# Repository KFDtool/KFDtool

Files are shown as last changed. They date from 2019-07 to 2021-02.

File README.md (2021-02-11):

# [KFDtool](https://github.com/KFDtool/KFDtool)

Open Source P25 Key Fill Device

Compliant with P25 standards (TIA-102.AACD-A)

Purchase Hardware: [online store](https://kfdtool.com/store)

Download Software: [latest release](https://github.com/KFDtool/KFDtool/releases)

Release Notifications: [subscribe](https://kfdtool.com/newsletter)

Demonstration: [video](https://www.youtube.com/watch?v=Oioa3xTQoE0)

Software Manual: [view](doc/KFDtool_Manual.pdf)

Security Considerations: [view](doc/SECURITY_CONSIDERATIONS.md)

Features
--------

**Key Fill Device (KFD)**

The KFDtool software supports KFD features through the KFDtool hardware adapter (TWI/3WI/Three Wire Interface), as well as through a IP (UDP) connection (DLI/Data Link Independent interface).

Keys and groups of keys can be saved to an AES-256 encrypted key container file, which can then be selected and loaded into a target device in one operation.

Supported Manual Rekeying Features (TIA-102.AACD-A)

* 2.3.1 Keyload
* 2.3.2 Key Erase
* 2.3.3 Erase All Keys
* 2.3.4 View Key Info
* 2.3.5 View Individual RSI
* 2.3.6 Load Individual RSI
* 2.3.7 View KMF RSI
* 2.3.8 Load KMF RSI
* 2.3.9 View MNP
* 2.3.10 Load MNP
* 2.3.11 View Keyset Info
* 2.3.12 Activate Keyset

Motorola refers to the P25 standard 3 wire interface (3WI) keyload protocol as ASTRO 25 mode or CKR mode.

The legacy Motorola proprietary keyloading formats SECURENET and ASN (Advanced SECURENET) are **NOT** supported by KFDtool. PID mode is also used to refer to ASN mode.

Key validators/generators are available for the following algorithms:

* AES-256 (Algorithm ID 0x84)
* DES-OFB (Algorithm ID 0x81)
* DES-XL (Algorithm ID 0x9F)
* ADP/RC4 (Algorithm ID 0xAA)

**Mobile Radio (MR) Emulator**

The KFDtool software only supports MR Emulator features through the KFDtool hardware adapter (TWI/3WI/Three Wire Interface) at this time.

This mode allows another keyloader to be connected to the KFDtool, and the keys retrieved.

Supported Manual Rekeying Features (TIA-102.AACD-A)

* 2.3.1 Keyload

Radio Compatibility
-------------------

*Any statements of compatibility do not imply endorsement by the vendor. Testing has not been performed by the vendor themselves.*

**A detailed list of compatible radios and adapters is available [here](doc/RADIO_COMPATIBILITY.md).**

Radios that are compatible with Motorola KVL3000/KVL3000+/KVL4000/KVL5000 keyloaders in ASTRO 25 mode should be compatible with KFDtool.

Keyloading cables made for other radios with MX (Motorola KVL) connectors can be modified by soldering an AC101 or AC102 Hirose pigtail in parallel with the MX connector according to [these](doc/MX_CONN_MOD_NOTES.md) instructions.

Operations encapsulated with encryption (commonly referred to as FIPS mode) are not supported at this time for either the KFD or MR emulation modes.

Hardware
--------

Assembled and tested KFDtool hardware is available from me directly. I can ship internationally. Please visit the [online store](https://kfdtool.com/store) to place an order.

**Proceeds from hardware sales enables me to further develop the software.**

| Part Number | Description |
| :---: | --- |
| KFD100 | Single Hirose port USB key fill device (includes 1 m / 3 ft USB A to USB B cable) |
| AC100 | 6 pin male plug Hirose to 6 pin male plug Hirose cable (0.5 m / 1.5 ft) |
| AC101 | 6 pin male plug Hirose pigtail for custom cables (0.5 m / 1.5 ft) |
| AC102 | 6 pin female jack Hirose pigtail for custom cables (0.5 m / 1.5 ft) |
| AC103 | Motorola R2670 compatible adapter (0.15 m / 6 in) |
| AC104 | Kenwood KPG-115 compatible adapter (0.15 m / 6 in) |
| AC105 | 4 way female jack passive Hirose splitter |
| AC106 | Kenwood KPG-93 compatible adapter (0.15 m / 6 in) |
| AC107 | Motorola XTS4000 compatible adapter (0.15 m / 6 in) |
| AC108 | Aeroflex/IFR 2975 compatible adapter (0.15 m / 6 in) |
| AC109 | Harris XG-100P/XL-150P/XL-185P/XL-200P compatible adapter |

OS Compatibility
----------------

* KFDtool software supports 32-bit and 64-bit Windows 7, Windows 8.1, and Windows 10

* The .NET Framework 4.7.2 or later compatible must be installed

* **The use of a virtual machine with USB passthrough is NOT supported at this time**
    * Changing the USB controller from USB 2.0 mode to USB 3.0 mode has been reported to resolve the issue
    * Do not attempt to update the adapter firmware or initialize an adapter using USB passthrough

Documentation
-------------

* [Software Changelog](doc/SW_CHANGELOG.txt)
* [Firmware Changelog](doc/FW_CHANGELOG.txt)
* [Hardware Changelog](doc/HW_CHANGELOG.txt)
* [Radio Compatibility](doc/RADIO_COMPATIBILITY.md)
* [TWI Cable Assembly Notes](doc/TWI_CABLE_ASSY_NOTES.md)
* [MX Connector Modification Notes](doc/MX_CONN_MOD_NOTES.md)
* [Developer Notes](doc/DEV_NOTES.md)
* [Security Considerations](doc/SECURITY_CONSIDERATIONS.md)

Contributors
------------

* [Daniel Dugger](https://github.com/duggerd)
* [Matt Ames](https://github.com/mattames)

License / Legal
---------------

KFDtool software, firmware, and hardware is distributed under the MIT License (see [LICENSE.txt](LICENSE.txt)).

KFDtool is a trademark of Florida Computer and Networking, Inc.

All product names, trademarks, registered trademarks, logos, and brands are property of their respective owners. All company, product, and service names used are for identification purposes only. Use of these names, trademarks, logos, and brands does not imply endorsement.

Note about hardware:

I request that no one else manufactures identical or compatible units **and sells them to others while I am still doing so** - I have put quite a bit of my own money into developing this hardware. I am totally fine with someone making a unit for themselves or a couple of extras to give to their friends, just that they don't charge for them. Proceeds from hardware sales enables me to further develop the software.

Included open-source components:

Software (see [doc/SW_LICENSE.txt](doc/SW_LICENSE.txt)):

* [NLog](https://github.com/NLog/NLog) - MIT License
* [Mono.Options](https://github.com/mono/mono/blob/master/mcs/class/Mono.Options/Mono.Options/Options.cs) - MIT License
* [HidLibrary](https://github.com/mikeobrien/HidLibrary) - MIT License
* [Microsoft Reference Source](https://github.com/microsoft/referencesource) - MIT License
* [InnovasubBSL430](https://github.com/corentinaltepe/InnovasubBSL430) - GPL v3+ License
* Texas Instruments - BSD 3 Clause License

Firmware (see [doc/FW_LICENSE.txt](doc/FW_LICENSE.txt)):

* Texas Instruments - BSD 3 Clause License

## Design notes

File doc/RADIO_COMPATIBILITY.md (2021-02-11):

# Compatibility

*Any statements of compatibility do not imply endorsement by the vendor. Testing has not been performed by the vendor themselves.*

## Three Wire Interface (TWI)

### Key Fill Device (KFD)

#### Adapter Compatibility

A vendor specific adapter or cable is required for most radios.

**The following adapters or cables are tested compatible with KFDtool:**

| Adapter | Device |
| --- | --- |
| KFDtool AC100 + KFDtool AC103 | Motorola R2670A/B Communications System Analyzer |
| KFDtool AC100 + KFDtool AC104 | Kenwood NX-5700/5800/5900 Mobile |
| KFDtool AC100 + KFDtool AC106 | Kenwood NX-5200/5300/5400 Portable |
| KFDtool AC100 + KFDtool AC107 | Motorola XTS4000 Portable |
| KFDtool AC100 + KFDtool AC108 | Aeroflex/IFR 2975 Radio Test Set |
| KFDtool AC100 + KFDtool AC109 | Harris XG-100P/XL-150P/XL-185P/XL-200P Portable |
| KFDtool AC100 + Motorola NTN8613 | Motorola XTS Portable (excluding XTS4000) |
| KFDtool AC100 + Motorola HKN6182 | Motorola GCAI Mobile (O CH, M CH, CAN TIB) |
| KFDtool AC100 + Motorola NNTN7869 | Motorola APX Portable |
| KFDtool AC100 + Motorola TRN7414/5880219R01 | Motorola W CH, DB25 TIB |
| KFDtool AC100 + Motorola NTN5664D | Motorola ASTRO Saber Portable |

#### Radio Compatibility

**Tested Compatible (with a passive adapter that does not alter the protocol):**

Motorola:

* APX (MACE) Portable/Mobile
* ASTRO 25 (MACE UCM) Portable/Mobile
* ASTRO 25 (ARMOR UCM) Portable/Mobile
* ASTRO (UCM/EMC Firmware Version 3.XX, Portable Host Firmware Version R07+, Mobile Host Firmware Version R11+) Portable/Mobile

Harris:

* XL-200P Portable
* XG-100P Portable
* XG-100M Mobile
* XG-75M/M7300 Mobile

Kenwood:

* NX-5200/5300/5400 Portable
* NX-5700/5800/5900 Mobile

EF Johnson:

* VP6000 Portable
* VP600 Portable
* 5100 Portable
* VM7000 Mobile
* VM900 Mobile
* 5300 Mobile

BK/Relm:

* KNG2 Portable
* KNG Portable

Thales/Racal:

* Liberty/PRC7332 Portable
* 25/PRC6894 Portable

Vertex Standard:

* VX-P820 Portable

Aeroflex/IFR:

* 2975 Radio Test Set

General Dynamics (Motorola Test Equipment Products):

* R2670A/B Communications System Analyzer

**Untested Compatible (with a passive adapter that does not alter the protocol):**

Harris:

* XL-185P Portable
* XL-150P Portable
* XG-75P Portable
* XG-25P Portable
* P7300 Portable
* P5500 Portable
* P5400 Portable

Kenwood:

* TK-5210/5310/5410(D) Portable
* TX-5220/5320 Portable
* TK-5710/5810 Mobile
* TK-5720/5820 Mobile

Icom:

* F7000 Portable
* F7500 Mobile
* F70/F80 Portable
* F1721/F2821 Mobile
* F9011/F9021 Portable
* F9511/F9521 Mobile

EF Johnson:

* VP5000 Portable
* VP900 Portable
* VM6000 Mobile
* VM5000 Mobile

BK/Relm:

* BKR 9000 Portable
* KNG Mobile

GME:

* CM60 Mobile

Aeroflex/IFR:

* 3920(B) Radio Test Set

Christine Wireless:

* TKMD

**Untested Compatible (with an active adapter that translates P25 standard 3WI keyload to/from their proprietary protocol):**

Tait:

* TP9400 Portable
* TP9100 Portable
* TM8200/TM8100 Mobile

**Not Compatible:**

Motorola:

* APX1000 Portable (no encryption support)
* APX900 Portable (loaded over USB programming cable in DLI mode)

Harris:

* P7200 Portable (loaded over serial with proprietary software)
* P7100 Portable (loaded over serial with proprietary software)

Unication:

* G4/G5 Pager (loaded over USB with proprietary software)
* U3 Portable (loaded over USB with proprietary software)

Other:

* Radios not supporting encryption (duh)

### Mobile Radio (MR) Emulator

#### Adapter Compatibility

A vendor specific adapter or cable is required for most keyloaders.

**The following adapters or cables are tested compatible with KFDtool:**

| Adapter | Device |
| --- | --- |
| Motorola TKN8531 | Motorola KVL |

#### Keyloader Compatibility

**Tested Compatible (with a passive adapter that does not alter the protocol):**

Motorola:

* KVL5000
* KVL4000
* KVL3000+
* KVL3000

**Untested Compatible (with a passive adapter that does not alter the protocol):**

Icom:

* KVL125

Benelec:

* BKL5000

Christine Wireless:

* TKMD

**Untested Compatible (with an active adapter that translates P25 standard 3WI keyload to/from their proprietary protocol):**

EF Johnson:

* SMA (2nd generation)
* SMA (1st generation)

Tait:

* KFD (2nd generation)
* KFD (1st generation)

**Not Compatible:**

Motorola:

* T series keyloaders

## Data Layer Independent (DLI)

### Key Fill Device (KFD)

#### Radio Compatibility

**Tested Compatible**

Motorola:

* APX900 Portable

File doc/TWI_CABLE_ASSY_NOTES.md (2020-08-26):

6 Pin Hirose Connector
----------------------

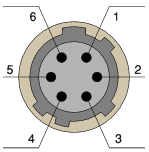
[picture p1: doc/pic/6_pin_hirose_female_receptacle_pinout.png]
pinout


View:

* Female receptacle/jack viewed from mating face
* Male plug solder cups viewed from assembly face

Pinout map / wire color map:

* 1 - RED (N/C)
* 2 - GRN (DATA)
* 3 - YEL (SENSE)
* 4 - BLK (GND)
* 5 - WHT (N/C)
* 6 - BLU (N/C)

6 Pin Male Plug Hirose P/N: HR10A-7P-6P(73)

6 Pin Female Jack Hirose P/N: HR10A-7J-6S(73)

Cable Retention Crimp Tool Hirose P/N: HR10A-TC-02

5 Pin Amp Connector
-------------------

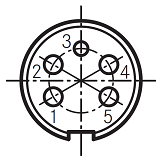
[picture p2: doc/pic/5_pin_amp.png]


View:

* Female receptacle/jack viewed from mating face
* Male plug solder cups viewed from assembly face

5 Pin Male Plug (silver plated) Amp P/N: T3360001U

5 Pin Male Plug (gold plated) Amp P/N: T3360018U

8 Pin 8P8C Connector
--------------------

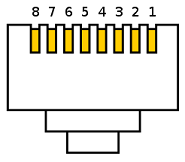
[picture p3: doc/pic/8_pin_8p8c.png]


View:

* Male plug contacts from mating face

Kenwood Portable Accessory Connector
------------------------------------

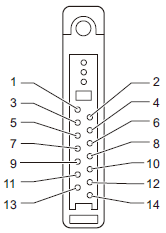
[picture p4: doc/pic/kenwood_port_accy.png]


View:

* Female jack contacts from mating face (radio side)

Motorola XTS4000 Accessory Connector
------------------------------------

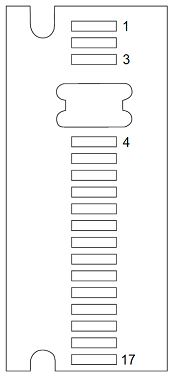
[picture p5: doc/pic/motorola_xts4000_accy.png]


View:

* Female jack contacts from mating face (radio side)

15 Pin DSUB Connector (2 row)
-----------------------------

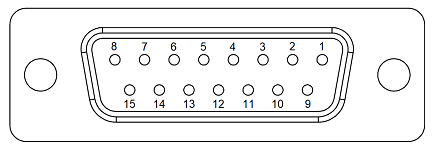
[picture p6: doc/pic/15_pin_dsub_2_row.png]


View:

* Male plug solder cups viewed from assembly face

AC100
-----

* 6 pin male plug Hirose to 6 pin male plug Hirose cable
* Wired straight through (pin 1 to pin 1, pin 2 to pin 2, etc)
* Pins 1, 5, and 6 are electrically connected in the cable assembly, however are not connected inside the KFDtool adapter

AC101
-----

* 6 pin male plug Hirose pigtail
* Pins 1, 5, and 6 are electrically connected in the cable assembly, however are not connected inside the KFDtool adapter

AC102
-----

* 6 pin female jack Hirose pigtail
* Pins 1, 5, and 6 are electrically connected in the cable assembly, however are not connected inside the KFDtool adapter

AC103
-----

* 6 pin female jack Hirose to 5 pin male plug Amp
* Equivalent to Motorola TKN8210 cable

Pinout:

* Amp Pin 1 - Hirose Pin 5
* Amp Pin 2 - Hirose Pin 1
* Amp Pin 3 - Hirose Pin 2
* Amp Pin 4 - Hirose Pin 4
* Amp Pin 5 - Hirose Pin 4

AC104
-----

* 6 pin female jack Hirose to 8 pin male plug 8P8C
* Equivalent to Kenwood KPG-115 cable

Pinout:

* 8P8C Pin 1 - Hirose Pin 4
* 8P8C Pin 2 - Hirose Pin 2
* 8P8C Pin 5 - (Cathode) Schottky Diode (Anode) - Hirose Pin 2
* 8P8C Pin 6 - Hirose Pin 4

AC106
-----

* 6 pin female jack Hirose to male Kenwood portable accessory connector
* Equivalent to Kenwood KPG-93 cable

Pinout:

* Accessory Pin 1 - Hirose Pin 4
* Accessory Pin 8 - Hirose Pin 4
* Accessory Pin 10 - Hirose Pin 4
* Accessory Pin 12 - (Cathode) Schottky Diode (Anode) - Hirose Pin 2
* Accessory Pin 13 - Hirose Pin 2

AC107
-----

* 6 pin female jack Hirose to male Motorola XTS4000 accessory connector
* Equivalent to Motorola CKN6886/0182297T15 cable

Pinout:

* Accessory Pin 1 - Hirose Pin 4
* Accessory Pin 8 - Hirose Pin 4
* Accessory Pin 9 - Hirose Pin 2

AC108
-----

* 6 pin female jack Hirose to male 15 pin DSUB plug (2 row)
* Equivalent to Aeroflex/IFR cable 51190/6041-4201-200
* Backshell must have a low profile due to faceplate protrusion

Pinout:

* DB15 pin 5 - Hirose Pin 2
* DB15 pin 7 - Hirose Pin 4
* DB15 pin 8 - 2k Resistor - Hirose Pin 2
* DB15 pin 13 - Hirose Pin 2

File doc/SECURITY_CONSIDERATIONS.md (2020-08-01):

# Security Considerations

* The KFDtool as a computer peripheral has several important considerations to keep in mind when secure keyloading is required.
    * What this means
        * Because the KFDtool keyloader is made up of a USB peripheral and software for use on a Windows PC, precautions have to be taken to preserve the integrity of the encryption keys due to the complex nature of the systems involved.

* The following points are only valid with unmodified software, firmware, and hardware. With physical access to the PC or adapter, the software, firmware, or hardware could be modified to covertly retain the plaintext keying material.
    * What this means
        * With physical access to the KFDtool adapter or computer running the KFDtool software, someone could modify them in a way to record or transmit the encryption keys without your knowledge. Therefore, you should physically secure the KFDtool adapter and the computer used for keyloading.

* Plaintext keying material is present in the PC's RAM, over the USB connection, in the adapter's RAM, and over the keyload connection. Therefore, you must trust the PC that the software is running on, or air gap it.
    * What this means
        * If the computer you use for keyloading is connected to a network, it is possible that the encryption keys could be accessed without your knowledge due to vulnerabilities in Windows or other software installed on your computer. Therefore, it is recommended that you use a computer that is not connected to any networks, and that you only install software and connect devices to it that you trust.

* It is possible that plaintext keying material in the PC's RAM is paged out to disk. It is also possible that Windows crash dumps may contain plaintext keying material. Therefore, it is recommended that the PC's hard drive is protected using full disk encryption such as BitLocker and powered off when unattended.
    * What this means
        * Windows is a complex operating system, and there are many ways for the encryption keys to end up on the hard drive without your knowledge. Therefore, encrypting the hard drive of the computer you use for keyloading is a good idea as it provides another layer of security against unauthorized users accessing the encryption keys without your knowledge.

* After the KFDtool adapter has been disconnected from the USB port, any residual plaintext keying material present in the microcontroller's RAM will be lost.
    * What this means
        * When unplugging the KFDtool adapter from the computer, any encryption keys are lost due to the memory type used. The KFDtool adapter by design does not store any encryption keys.

* When certain non-default logging is enabled, plaintext keying material is written out to the log file on disk. This logging should only be enabled when diagnostic information needs to be collected, and only used with dummy keying material.
    * What this means
        * There are options in the KFDtool software configuration files that can be set to write detailed information to the hard drive for use to diagnose issues. If you are directed to change these files to enable logging to diagnose an issue, understand that the keys you use may be included in these logs. Therefore, you should not use your production keys when collecting these logs.

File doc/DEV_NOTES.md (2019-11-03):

# Developer Documentation

## Hardware

### Test Points

The PT100 PCB has 15 test points, numbered T1 to T15.

NOTE: T1, T2, T4, T5, T6, T7, T8, T9, T10, T11 are referenced to `GND` (T3). T4, T5, T6, T7, T8, T9, T10, T11 are 3.3V level signals.

NOTE: T12, T13, T15 are referenced to `GNDISO` (T14). T12, T13, T15 are 5V level signals.

* T1 - `5V`
    * USB 5V DC power rail
    * Used for MCU USB circuitry and digital isolator power supply

* T2 - `3V3`
    * Regulated 3.3V DC power rail
    * Used for MCU core/ports and EEPROM

* T3 - `GND`
    * Ground for PC connected circuitry (MCU/EEPROM)

* T4 - `SBWTDIO`
    * MCU debug/programming interface, connects to SBW RST on TI LaunchPad ez-FET header

* T5 - `SBWTCK`
    * MCU debug/programming interface, connects to SBW TST on TI LaunchPad ez-FET header

* T6 - `GPIO1`
    * General purpose I/O for debugging, pin P4.4 on MCU, hardware serial port on MCU (TX)
    * Currently outputs a LOW when interrupts are enabled, and outputs a HIGH when interrupts are disabled (during reception of byte during timer operation)

* T7 - `GPIO2`
    * General purpose I/O for debugging, pin P4.5 on MCU, hardware serial port on MCU (RX)
    * Currently toggles state when the `MCU_DATA_IN_3V3` signal is being sampled

* T8 - `MCU_DATA_OUT_3V3`
    * Controls transistor for DATA signal
    * `MCU_DATA_OUT_3V3` LOW = transistor off = DATA line pulled HIGH (`5VISO`) by pull up resistor
    * `MCU_DATA_OUT_3V3` HIGH = transistor on = DATA line pulled LOW (`GNDISO`) by transistor

* T9 - `MCU_DATA_IN_3V3`
    * Level shifted version of `KFD_DATA_IN`

* T10 - `MCU_SENSE_OUT_3V3`
    * Controls transistor for SENSE signal
    * `MCU_SENSE_OUT_3V3` LOW = transistor off = SENSE line pulled HIGH (`5VISO`) by pull up resistor
    * `MCU_SENSE_OUT_3V3` HIGH = transistor on = SENSE line pulled LOW (`GNDISO`) by transistor

* T11 - `MCU_SENSE_IN_3V3`
    * Level shifted version of `KFD_SENSE_IN`

* T12 - `KFD_DATA_IN`
    * Target DATA signal

* T13 - `KFD_SENSE_IN`
    * Target SENSE signal

* T14 - `GNDISO`
    * Target isolated ground

* T15 - `5VISO`
    * Target isolated 5V DC power rail

### External Logic Analyzer

A external logic analyzer can be connected to monitor the TWI signals independent of the KFDtool. The TWI physical protocol is close to a UART signal, and therefore UART protocol decoders of logic analyzers can be used.

There is no stop bit in the TWI protocol, where a stop bit is part of the UART protocol. The logic analyzer reports a framing error where it expects a stop bit, however this can be safely ignored.

The following screenshots are of the Saleae logic analyzer software.

* Ground - connected to T3
* Channel 00 "GPIO1" - connected to T6
* Channel 01 "GPIO2" - connected to T7
* Channel 02 "DATA_OUT" - connected to T8
* Channel 03 "DATA_IN" - connected to T9
* Channel 04 "SENSE_OUT" - connected to T10
* Channel 05 "SENSE_IN" - connected to T11
* Trigger - Channel 03 "DATA_IN" falling edge

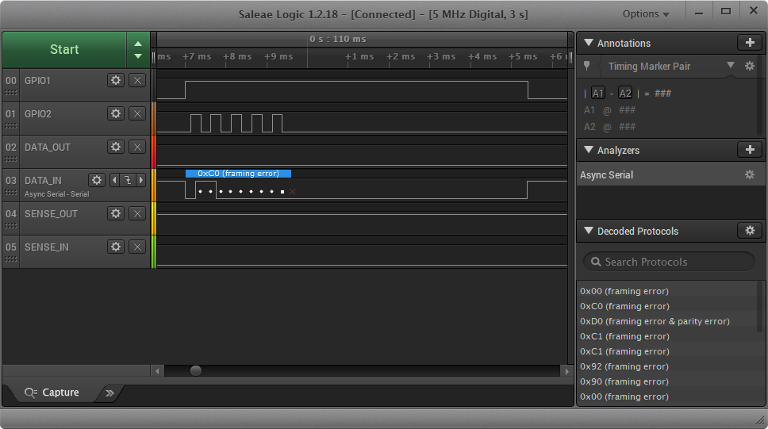
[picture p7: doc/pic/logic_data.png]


Async serial (UART) analyzer settings:

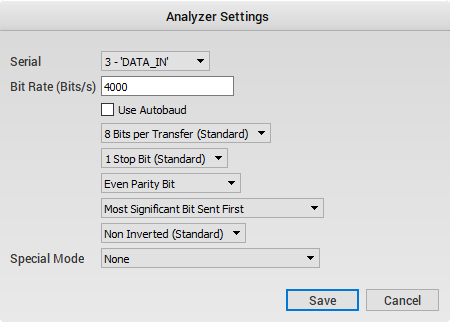
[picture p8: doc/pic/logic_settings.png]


## Firmware

### Development/Build Environment

Firmware is built using TI CCS 9.

## Software

### Development/Build Environment

Software is built with Microsoft Visual Studio 2019.

### Command Line

The KFDtoolCmd.exe program contains command line utilities. The following utilities are available:

* read
    * Description: Read bytes from the TWI interface
    * Usage: `-read -port COM#`

* create
    * Description: Create a firmware update package
    * Usage: `-create -input generate.xml -output package`
    * Example: [generate.xml](../sw/control/KFDtool.Cmd/generate.xml)

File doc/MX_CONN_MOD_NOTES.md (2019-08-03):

MX Connector
------------

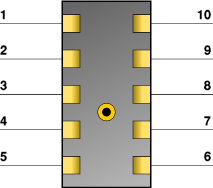
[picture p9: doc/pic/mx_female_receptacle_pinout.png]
pinout


View (note vertically offset center keying peg location):

* Female receptacle viewed from mating face
* Male plug solder cups viewed from assembly face

Pinout map:

* Hirose Pin 2 (GRN) - MX Pin 8 (DATA)
* Hirose Pin 3 (YEL) - MX Pin 10 (SENSE)
* Hirose Pin 4 (BLK) - MX Pin 9 (GND)

Hirose pins 1, 5, and 6 should NOT be connected to anything (leave floating)

Do not attach both the MX connector to a keyloader and the Hirose connector to the KFDtool at the same time. It will not damage anything, however, keyload operations may fail.

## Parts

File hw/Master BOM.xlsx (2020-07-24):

Description | Designator | Manufacturer Name | Manufacturer P/N | Quantity | Vendor 1 Name | Vendor 1 P/N | Vendor 2 Name | Vendor 2 P/N
KFD100 1.0 [OBSOLETE]
BOX ALUM NATURAL 2.36"L X 1.67"W | N/A | Hammond Manufacturing | 1455D601 | 1 | Digi-Key | HM1358-ND | Mouser | 546-1455D601
Main PCB | N/A | CUSTOM | PT100 REV C | 1 | N/A | N/A | N/A | N/A
CAP CER 10PF 50V C0G/NP0 0603 | C4,C5 | Samsung Electro-Mechanics | CL10C100JB8NNNC | 2 | Digi-Key | 1276-1027-1-ND | TBD | TBD
CAP CER 33PF 50V C0G/NP0 0603 | C11,C12 | Samsung Electro-Mechanics | CL10C330JB8NNNC | 2 | Digi-Key | 1276-1070-1-ND | TBD | TBD
CAP CER 100PF 3KV C0G 1812 | C23 | TDK Corporation | C4532C0G3F101K160KA | 1 | Digi-Key | 445-2376-1-ND | Mouser | 810-C4532C0G3F101K
CAP CER 1000PF 50V C0G/NP0 0603 | C13 | Samsung Electro-Mechanics | CL10C102JB8NNNC | 1 | Digi-Key | 1276-1091-1-ND | TBD | TBD
CAP CER 0.1UF 50V X7R 0603 | C1,C3,C6,C7,C9,C10,C18,C20,C21,C24 | Samsung Electro-Mechanics | CL10B104KB8NNNC | 10 | Digi-Key | 1276-1000-1-ND | TBD | TBD
CAP CER 0.22UF 16V X7R 0603 | C14,C16 | Samsung Electro-Mechanics | CL10B224KO8NNNC | 2 | Digi-Key | 1276-1112-1-ND | TBD | TBD
CAP CER 0.47UF 25V X7R 0603 | C15 | Samsung Electro-Mechanics | CL10B474KA8NFNC | 1 | Digi-Key | 1276-2082-1-ND | TBD | TBD
CAP CER 4.7UF 10V X5R 0603 | C17 | Samsung Electro-Mechanics | CL10A475KP8NNNC | 1 | Digi-Key | 1276-1044-1-ND | TBD | TBD
CAP CER 10UF 10V X5R 0603 | C2,C8,C19,C22 | Samsung Electro-Mechanics | CL10A106KP8NNNC | 4 | Digi-Key | 1276-1192-1-ND | TBD | TBD
DIODE ZENER 5.6V 225MW SOT23-3 | D1,D2 | ON Semiconductor | BZX84C5V6LT1G | 2 | Digi-Key | BZX84C5V6LT1GOSCT-ND | Mouser | 863-BZX84C5V6LT1G
LED IND 3MM RA 565NM GREEN DIFF | LED1 | Kingbright | WP934CB/GD | 1 | Digi-Key | 754-1297-ND | Mouser | 604-WP934CB/GD
PTC RESET FUSE 60V 500MA 2920 | F1 | Bel Fuse Inc. | 0ZCF0050FF2C | 1 | Digi-Key | 507-1741-1-ND | Mouser | 530-0ZCF0050FF2C
FERRITE BEAD 120 OHM 0603 1LN | FB1 | Murata Electronics North America | BLM18PG121SN1D | 1 | Digi-Key | 490-1037-1-ND | Mouser | 81-BLM18PG121SN1D
FERRITE BEAD 1.8 KOHM 0603 1LN | FB2,FB3 | Taiyo Yuden | BK1608LM182-T | 2 | Digi-Key | 587-1892-1-ND | Mouser | 963-BK1608LM182-T
CONN RCPT USB2.0 TYPEB 4POS R/A | J1 | Amphenol FCI | 61729-1011BLF | 1 | Digi-Key | 609-3657-ND | Mouser | 649-61729-1011BLF
CONN HEADER R/A 3POS 1.27MM | J2,J3 | Harwin Inc. | M50-3930342 | 2 | Digi-Key | 952-3615-ND | Mouser | 855-M50-3930342
TRANS NPN 40V 0.2A SOT23 | Q1,Q2 | ON Semiconductor | MMBT3904LT1G | 2 | Digi-Key | MMBT3904LT1GOSCT-ND | Mouser | 863-MMBT3904LT1G
RES SMD 27 OHM 1% 1/10W 0603 | R2,R3 | Yageo | RC0603FR-0727RL | 2 | Digi-Key | 311-27.0HRCT-ND | Mouser | 603-RC0603FR-0727RL
RES SMD 100 OHM 1% 1/10W 0603 | R6 | Yageo | RC0603FR-07100RL | 1 | Digi-Key | 311-100HRCT-ND | Mouser | 603-RC0603FR-07100RL
RES SMD 150 OHM 1% 1/10W 0603 | R10,R13 | Yageo | RC0603FR-07150RL | 2 | Digi-Key | 311-150HRCT-ND | Mouser | 603-RC0603FR-07150RL
RES SMD 470 OHM 1% 1/10W 0603 | R1 | Yageo | RC0603FR-07470RL | 1 | Digi-Key | 311-470HRCT-ND | Mouser | 603-RC0603FR-07470RL
RES SMD 1K OHM 1% 1/10W 0603 | R9,R12 | Yageo | RC0603FR-071KL | 2 | Digi-Key | 311-1.00KHRCT-ND | Mouser | 603-RC0603FR-071KL
RES SMD 1.4K OHM 1% 1/10W 0603 | R5 | Yageo | RC0603FR-071K4L | 1 | Digi-Key | 311-1.40KHRCT-ND | Mouser | 603-RC0603FR-071K4L
RES SMD 10K OHM 1% 1/10W 0603 | R8,R11,R15 | Yageo | RC0603FR-0710KL | 3 | Digi-Key | 311-10.0KHRCT-ND | Mouser | 603-RC0603FR-0710KL
RES SMD 30K OHM 1% 1/10W 0603 | R14 | Yageo | RC0603FR-0730KL | 1 | Digi-Key | 311-30.0KHRCT-ND | Mouser | 603-RC0603FR-0730KL
RES SMD 47K OHM 1% 1/10W 0603 | R4 | Yageo | RC0603FR-0747KL | 1 | Digi-Key | 311-47.0KHRCT-ND | Mouser | 603-RC0603FR-0747KL
RES SMD 1M OHM 1% 1/10W 0603 | R7 | Yageo | RC0603FR-071ML | 1 | Digi-Key | 311-1.00MHRCT-ND | Mouser | 603-RC0603FR-071ML
SWITCH TACTILE SPST-NO 0.05A 12V | S1 | E-Switch | TL3340AF160QG | 1 | Digi-Key | EG4627CT-ND | Mouser | 612-TL3340AF160QG
IC REG LIN 3.3V 400MA SOT223-4 | U1 | Texas Instruments | LM2937IMP-3.3/NOPB | 1 | Digi-Key | LM2937IMP-3.3/NOPBCT-ND | Mouser | 926-LM2937IMP3.3NOPB
IC MCU 16BIT 128KB FLASH 80LQFP | U2 | Texas Instruments | MSP430F5529IPNR | 1 | Digi-Key | 296-27306-1-ND | Mouser | 595-MSP430F5529IPNR
DGTL ISO 2.5KV 4CH 24SSOP | U3 | Analog Devices Inc. | ADUM5412BRSZ | 1 | Digi-Key | ADUM5412BRSZ-ND | Mouser | 584-ADUM5412BRSZ
IC EEPROM 1M SPI 20MHZ 8SOIC | U4 | Microchip Technology | AT25M01-SSHM-T | 1 | Digi-Key | AT25M01-SSHM-TCT-ND | Mouser | 556-AT25M01-SSHM-T
CRYSTAL 24.0000MHZ 18PF SMD | Y1 | Abracon LLC | ABLS2-24.000MHZ-D4YF-T | 1 | Digi-Key | 535-9881-1-ND | Mouser | 815-ABLS2-24-D4YF-T
Front Panel (Hirose) PCB | N/A | CUSTOM | PT101 REV C | 1 | N/A | N/A | N/A | N/A
Screw Hex Zinc Plt Steel, 6-32, 1/4 (1) | N/A | McMaster-Carr | 91306A320 | 4 | McMaster-Carr | 91306A320 | N/A | N/A
Rear Panel (USB) PCB | N/A | CUSTOM | PT102 REV C | 1 | N/A | N/A | N/A | N/A
Hirose Interposer PCB | N/A | CUSTOM | PT103 REV A | 1 | N/A | N/A | N/A | N/A
CONN RCPT FMALE 6POS SOLDER | N/A | Hirose Electric Co Ltd | HR10A-7R-6SB(73) | 1 | Digi-Key | HR1608-ND | Mouser | 798-HR10A-7R-6SB73
CONN RCPT 3POS 0.05 GOLD PCB | N/A | Harwin Inc. | M50-3030342 | 2 | Digi-Key | 952-3575-ND | Mouser | 855-M50-3030342
KFD100 1.1
BOX ALUM NATURAL 2.36"L X 1.67"W | N/A | Hammond Manufacturing | 1455D601 | 1 | Digi-Key | HM1358-ND | Mouser | 546-1455D601
Main PCB | N/A | CUSTOM | PT100 REV D | 1 | N/A | N/A | N/A | N/A
CAP CER 10PF 50V C0G/NP0 0603 | C4,C5 | Samsung Electro-Mechanics | CL10C100JB8NNNC | 2 | Digi-Key | 1276-1027-1-ND | TBD | TBD
CAP CER 33PF 50V C0G/NP0 0603 | C11,C12 | Samsung Electro-Mechanics | CL10C330JB8NNNC | 2 | Digi-Key | 1276-1070-1-ND | TBD | TBD
CAP CER 100PF 3KV C0G 1812 | C23 | TDK Corporation | C4532C0G3F101K160KA | 1 | Digi-Key | 445-2376-1-ND | Mouser | 810-C4532C0G3F101K
CAP CER 1000PF 50V C0G/NP0 0603 | C13 | Samsung Electro-Mechanics | CL10C102JB8NNNC | 1 | Digi-Key | 1276-1091-1-ND | TBD | TBD
CAP CER 0.1UF 50V X7R 0603 | C1,C3,C6,C7,C9,C10,C18,C20,C21,C24 | Samsung Electro-Mechanics | CL10B104KB8NNNC | 10 | Digi-Key | 1276-1000-1-ND | TBD | TBD
CAP CER 0.22UF 16V X7R 0603 | C14,C16 | Samsung Electro-Mechanics | CL10B224KO8NNNC | 2 | Digi-Key | 1276-1112-1-ND | TBD | TBD
CAP CER 0.47UF 25V X7R 0603 | C15 | Samsung Electro-Mechanics | CL10B474KA8NFNC | 1 | Digi-Key | 1276-2082-1-ND | TBD | TBD
CAP CER 4.7UF 10V X5R 0603 | C17 | Samsung Electro-Mechanics | CL10A475KP8NNNC | 1 | Digi-Key | 1276-1044-1-ND | TBD | TBD
CAP CER 10UF 10V X5R 0603 | C2,C8,C19,C22 | Samsung Electro-Mechanics | CL10A106KP8NNNC | 4 | Digi-Key | 1276-1192-1-ND | TBD | TBD
DIODE ZENER 5.6V 225MW SOT23-3 | D1,D2 | ON Semiconductor | BZX84C5V6LT1G | 2 | Digi-Key | BZX84C5V6LT1GOSCT-ND | Mouser | 863-BZX84C5V6LT1G
LED IND 3MM RA 565NM GREEN DIFF | LED1 | Kingbright | WP934CB/GD | 1 | Digi-Key | 754-1297-ND | Mouser | 604-WP934CB/GD
PTC RESET FUSE 60V 500MA 2920 | F1 | Bel Fuse Inc. | 0ZCF0050FF2C | 1 | Digi-Key | 507-1741-1-ND | Mouser | 530-0ZCF0050FF2C
FERRITE BEAD 120 OHM 0603 1LN | FB1 | Murata Electronics North America | BLM18PG121SN1D | 1 | Digi-Key | 490-1037-1-ND | Mouser | 81-BLM18PG121SN1D
FERRITE BEAD 1.8 KOHM 0603 1LN | FB2,FB3 | Taiyo Yuden | BK1608LM182-T | 2 | Digi-Key | 587-1892-1-ND | Mouser | 963-BK1608LM182-T
CONN RCPT USB2.0 TYPEB 4POS R/A | J1 | Amphenol FCI | 61729-1011BLF | 1 | Digi-Key | 609-3657-ND | Mouser | 649-61729-1011BLF
CONN HEADER R/A 3POS 1.27MM | J2, J3 | Harwin Inc. | M50-3930342 | 2 | Digi-Key | 952-3615-ND | Mouser | 855-M50-3930342
TRANS NPN 40V 0.2A SOT23 | Q1,Q2 | ON Semiconductor | MMBT3904LT1G | 2 | Digi-Key | MMBT3904LT1GOSCT-ND | Mouser | 863-MMBT3904LT1G
RES SMD 27 OHM 1% 1/10W 0603 | R2,R3 | Yageo | RC0603FR-0727RL | 2 | Digi-Key | 311-27.0HRCT-ND | Mouser | 603-RC0603FR-0727RL
RES SMD 100 OHM 1% 1/10W 0603 | R6 | Yageo | RC0603FR-07100RL | 1 | Digi-Key | 311-100HRCT-ND | Mouser | 603-RC0603FR-07100RL
RES SMD 150 OHM 1% 1/10W 0603 | R10,R13 | Yageo | RC0603FR-07150RL | 2 | Digi-Key | 311-150HRCT-ND | Mouser | 603-RC0603FR-07150RL
RES SMD 470 OHM 1% 1/10W 0603 | R1 | Yageo | RC0603FR-07470RL | 1 | Digi-Key | 311-470HRCT-ND | Mouser | 603-RC0603FR-07470RL
RES SMD 1K OHM 1% 1/10W 0603 | R9,R12 | Yageo | RC0603FR-071KL | 2 | Digi-Key | 311-1.00KHRCT-ND | Mouser | 603-RC0603FR-071KL
RES SMD 1.4K OHM 1% 1/10W 0603 | R5 | Yageo | RC0603FR-071K4L | 1 | Digi-Key | 311-1.40KHRCT-ND | Mouser | 603-RC0603FR-071K4L
RES SMD 10K OHM 1% 1/10W 0603 | R8,R11,R15 | Yageo | RC0603FR-0710KL | 3 | Digi-Key | 311-10.0KHRCT-ND | Mouser | 603-RC0603FR-0710KL
RES SMD 30K OHM 1% 1/10W 0603 | R14 | Yageo | RC0603FR-0730KL | 1 | Digi-Key | 311-30.0KHRCT-ND | Mouser | 603-RC0603FR-0730KL
RES SMD 47K OHM 1% 1/10W 0603 | R4 | Yageo | RC0603FR-0747KL | 1 | Digi-Key | 311-47.0KHRCT-ND | Mouser | 603-RC0603FR-0747KL
RES SMD 1M OHM 1% 1/10W 0603 | R7 | Yageo | RC0603FR-071ML | 1 | Digi-Key | 311-1.00MHRCT-ND | Mouser | 603-RC0603FR-071ML
SWITCH TACTILE SPST-NO 0.05A 12V | S1 | E-Switch | TL3340AF160QG | 1 | Digi-Key | EG4627CT-ND | Mouser | 612-TL3340AF160QG
IC REG LIN 3.3V 400MA SOT223-4 | U1 | Texas Instruments | LM2937IMP-3.3/NOPB | 1 | Digi-Key | LM2937IMP-3.3/NOPBCT-ND | Mouser | 926-LM2937IMP3.3NOPB
IC MCU 16BIT 128KB FLASH 80LQFP | U2 | Texas Instruments | MSP430F5529IPNR | 1 | Digi-Key | 296-27306-1-ND | Mouser | 595-MSP430F5529IPNR
DGTL ISO 2.5KV 4CH 24SSOP | U3 | Analog Devices Inc. | ADUM5412BRSZ | 1 | Digi-Key | ADUM5412BRSZ-ND | Mouser | 584-ADUM5412BRSZ
IC EEPROM 1M SPI 20MHZ 8SOIC | U4 | Microchip Technology | AT25M01-SSHM-T | 1 | Digi-Key | AT25M01-SSHM-TCT-ND | Mouser | 556-AT25M01-SSHM-T
TVS DIODE 5.25V 17V SOT23-6 | U5 | STMicroelectronics | USBLC6-2SC6 | 1 | Digi-Key | 497-5235-1-ND | Mouser | 511-USBLC6-2SC6
CRYSTAL 24.0000MHZ 18PF SMD | Y1 | Abracon LLC | ABLS2-24.000MHZ-D4YF-T | 1 | Digi-Key | 535-9881-1-ND | Mouser | 815-ABLS2-24-D4YF-T
Front Panel (Hirose) PCB | N/A | CUSTOM | PT101 REV C | 1 | N/A | N/A | N/A | N/A
Screw Hex Zinc Plt Steel, 6-32, 1/4 (1) | N/A | McMaster-Carr | 91306A320 | 4 | McMaster-Carr | 91306A320 | N/A | N/A
Rear Panel (USB) PCB | N/A | CUSTOM | PT102 REV C | 1 | N/A | N/A | N/A | N/A
Hirose Interposer PCB | N/A | CUSTOM | PT103 REV A | 1 | N/A | N/A | N/A | N/A
CONN RCPT FMALE 6POS SOLDER | N/A | Hirose Electric Co Ltd | HR10A-7R-6SB(73) | 1 | Digi-Key | HR1608-ND | Mouser | 798-HR10A-7R-6SB73
CONN RCPT 3POS 0.05 GOLD PCB | N/A | Harwin Inc. | M50-3030342 | 2 | Digi-Key | 952-3575-ND | Mouser | 855-M50-3030342
AC100A
CABLE 6COND 28AWG BLK 153M (0.5M) | N/A | Tensility | 30-00510 | 1 | Digi-Key | T1347-153-ND | N/A | N/A
CONN PLUG MALE 6POS SOLDER CUP | N/A | Hirose Electric Co Ltd | HR10A-7P-6P(73) | 2 | Digi-Key | HR1586-ND | Mouser | 798-HR10A-7P-6P73
AC101A
CABLE 6COND 28AWG BLK 153M (0.5M) | N/A | Tensility | 30-00510 | 1 | Digi-Key | T1347-153-ND | N/A | N/A
CONN PLUG MALE 6POS SOLDER CUP | N/A | Hirose Electric Co Ltd | HR10A-7P-6P(73) | 1 | Digi-Key | HR1586-ND | Mouser | 798-HR10A-7P-6P73
AC102A
CABLE 6COND 28AWG BLK 153M (0.5M) | N/A | Tensility | 30-00510 | 1 | Digi-Key | T1347-153-ND | N/A | N/A
CONN JACK FMALE 6POS SOLDER CUP | N/A | Hirose Electric Co Ltd | HR10A-7J-6S(73) | 1 | Digi-Key | HR1601-ND | Mouser | 798-HR10A-7J-6S73
AC103A
CABLE 6COND 28AWG BLK 153M (0.15M) | N/A | Tensility | 30-00510 | 1 | Digi-Key | T1347-153-ND | N/A | N/A
CONN JACK FMALE 6POS SOLDER CUP | N/A | Hirose Electric Co Ltd | HR10A-7J-6S(73) | 1 | Digi-Key | HR1601-ND | Mouser | 798-HR10A-7J-6S73
CONN PLUG MALE DIN 5POS SLDR CUP | N/A | Amphenol Sine Systems Corp | T3360018U | 1 | Digi-Key | 361-1217-ND | N/A | N/A
AC104A [OBSOLETE]
CABLE 6COND 28AWG BLK 153M (0.15M) | N/A | Tensility | 30-00510 | 1 | Digi-Key | T1347-153-ND | N/A | N/A
CONN JACK FMALE 6POS SOLDER CUP | N/A | Hirose Electric Co Ltd | HR10A-7J-6S(73) | 1 | Digi-Key | HR1601-ND | Mouser | 798-HR10A-7J-6S73
CONN MOD PLUG 8P8C UNSHIELDED | N/A | Stewart Connector | 940-SP-3088 | 1 | Digi-Key | 380-1192-ND | Mouser | 530-940-SP-3088
AC104B
CABLE 6COND 28AWG BLK 153M (0.15M) | N/A | Tensility | 30-00510 | 1 | Digi-Key | T1347-153-ND | N/A | N/A
CONN JACK FMALE 6POS SOLDER CUP | N/A | Hirose Electric Co Ltd | HR10A-7J-6S(73) | 1 | Digi-Key | HR1601-ND | Mouser | 798-HR10A-7J-6S73
CONN MOD PLUG 8P8C UNSHIELDED | N/A | Stewart Connector | 940-SP-3088 | 1 | Digi-Key | 380-1192-ND | Mouser | 530-940-SP-3088
DIODE SCHOTTKY 40V SGL DO35 | N/A | Vishay Semiconductor Diodes | SD103A-TAP | 1 | Digi-Key | SD103A-TAPGICT-ND | Mouser | 78-SD103A-TAP
AC105A
BOX ABS BLACK 1.38"L X 1.38"W | N/A | Hammond Manufacturing | 1551MBK | 1 | Digi-Key | HM993-ND | Mouser | 546-1551MBK
CONN RCPT FMALE 6POS SOLDER CUP | N/A | Hirose Electric Co Ltd | HR10A-7R-6S(73) | 4 | Digi-Key | HR1594-ND | Mouser | 798-HR10A-7R-6S73
AC106A
CABLE 6COND 28AWG BLK 153M (0.15M) | N/A | Tensility | 30-00510 | 1 | Digi-Key | T1347-153-ND | N/A | N/A
CONN JACK FMALE 6POS SOLDER CUP | N/A | Hirose Electric Co Ltd | HR10A-7J-6S(73) | 1 | Digi-Key | HR1601-ND | Mouser | 798-HR10A-7J-6S73
Kenwood Portable Accessory Connector | N/A | N/A | N/A | 1 | N/A | N/A | N/A | N/A
DIODE SCHOTTKY 40V SGL DO35 | N/A | Vishay Semiconductor Diodes | SD103A-TAP | 1 | Digi-Key | SD103A-TAPGICT-ND | Mouser | 78-SD103A-TAP
AC107A
CABLE 6COND 28AWG BLK 153M (0.15M) | N/A | Tensility | 30-00510 | 1 | Digi-Key | T1347-153-ND | N/A | N/A
CONN JACK FMALE 6POS SOLDER CUP | N/A | Hirose Electric Co Ltd | HR10A-7J-6S(73) | 1 | Digi-Key | HR1601-ND | Mouser | 798-HR10A-7J-6S73
Motorola DTR700 Programming Cable | N/A | Motorola Solutions | 0105950U15 | 1 | N/A | N/A | N/A | N/A
AC108A
CABLE 6COND 28AWG BLK 153M (0.15M) | N/A | Tensility | 30-00510 | 1 | Digi-Key | T1347-153-ND | N/A | N/A
CONN JACK FMALE 6POS SOLDER CUP | N/A | Hirose Electric Co Ltd | HR10A-7J-6S(73) | 1 | Digi-Key | HR1601-ND | Mouser | 798-HR10A-7J-6S73
CONN D-SUB PLUG 15P SLDR CUP | N/A | Assmann WSW Components | A-DS 15 LL/Z | 1 | Digi-Key | AE10978-ND | N/A | N/A
CONN BACKSHELL 15POS 180DEG SHLD | N/A | Assmann WSW Components | AGP 15 G-ME | 1 | Digi-Key | AE11012-ND | N/A | N/A
RES 2K OHM 1/4W 1% AXIAL | N/A | Stackpole Electronics Inc | RNMF14FTC2K00 | 1 | Digi-Key | S2KCACT-ND | N/A | N/A

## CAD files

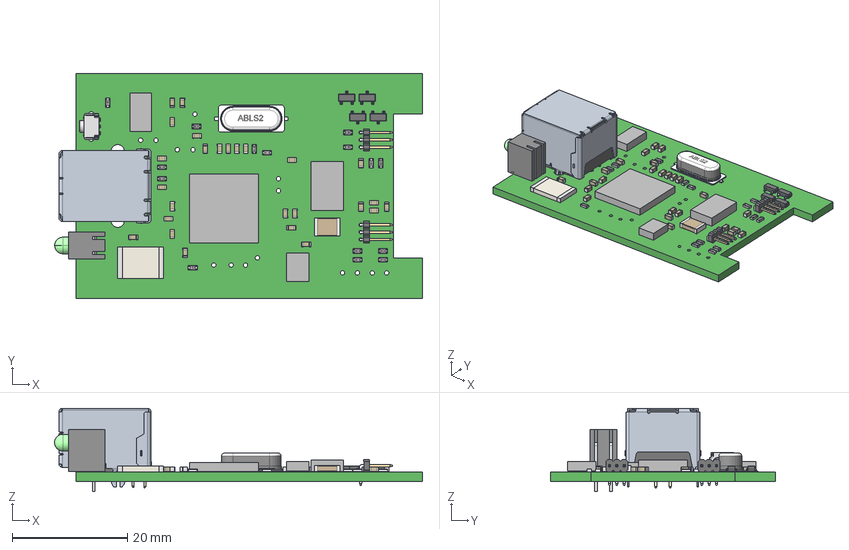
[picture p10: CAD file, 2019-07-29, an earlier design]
hw/KFD100/PT100 Main/REV C/out/PT100_3D_REV_C_2019-07-02_2.step
63.7 x 39.0 x 14.5 mm
Extruded x 7
0603_cap x 26
TL3340AF160QG
0603_resistor x 15
CAP_1812-1.1mm
sot-23-3-infineon x 4
934CB
ABLS2
M50-39303_MOULD x 2
M50-393_CONTACT x 6
FCI_61729-1011BLF

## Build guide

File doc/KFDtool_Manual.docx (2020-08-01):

# Contents

# Manual Revision History

Revision | Date | Description
1 | 2020-08-01 | Initial Release for 1.5.0

# Operation

## Overview

TODO

## Security Considerations

- The KFDtool as a computer peripheral has several important considerations to keep in mind when secure keyloading is required.
  - What this means
    - Because the KFDtool keyloader is made up of a USB peripheral and software for use on a Windows PC, precautions have to be taken to preserve the integrity of the encryption keys due to the complex nature of the systems involved.
- The following points are only valid with unmodified software, firmware, and hardware. With physical access to the PC or adapter, the software, firmware, or hardware could be modified to covertly retain the plaintext keying material.
  - What this means
    - With physical access to the KFDtool adapter or computer running the KFDtool software, someone could modify them in a way to record or transmit the encryption keys without your knowledge. Therefore, you should physically secure the KFDtool adapter and the computer used for keyloading.
- Plaintext keying material is present in the PC's RAM, over the USB connection, in the adapter's RAM, and over the keyload connection. Therefore, you must trust the PC that the software is running on, or air gap it.
  - What this means
    - If the computer you use for keyloading is connected to a network, it is possible that the encryption keys could be accessed without your knowledge due to vulnerabilities in Windows or other software installed on your computer. Therefore, it is recommended that you use a computer that is not connected to any networks, and that you only install software and connect devices to it that you trust.
- It is possible that plaintext keying material in the PC's RAM is paged out to disk. It is also possible that Windows crash dumps may contain plaintext keying material. Therefore, it is recommended that the PC's hard drive is protected using full disk encryption such as BitLocker and powered off when unattended.
  - What this means
    - Windows is a complex operating system, and there are many ways for the encryption keys to end up on the hard drive without your knowledge. Therefore, encrypting the hard drive of the computer you use for keyloading is a good idea as it provides another layer of security against unauthorized users accessing the encryption keys without your knowledge.
- After the KFDtool adapter has been disconnected from the USB port, any residual plaintext keying material present in the microcontroller's RAM will be lost.
  - What this means
    - When unplugging the KFDtool adapter from the computer, any encryption keys are lost due to the memory type used. The KFDtool adapter by design does not store any encryption keys.
- When certain non-default logging is enabled, plaintext keying material is written out to the log file on disk. This logging should only be enabled when diagnostic information needs to be collected, and only used with dummy keying material.
  - What this means
    - There are options in the KFDtool software configuration files that can be set to write detailed information to the hard drive for use to diagnose issues. If you are directed to change these files to enable logging to diagnose an issue, understand that the keys you use may be included in these logs. Therefore, you should not use your production keys when collecting these logs.

## Features

### Overall

#### Title Bar

Displays the KFDtool software version and selected function.

#### Menu Items

##### File -> Exit

Exits the application.

##### Help -> Manual

Opens the PDF manual in the system’s default PDF viewer.

##### Help -> Website

Opens the KFDtool website in the system’s default web browser.

##### Help -> About

Displays the software version and copyright information in a dialog.

### Container

#### Overview

The container feature allows individual keys and groups of keys to be stored and used in other features of the software. The container can be saved on disk and opened on the same or another machine.

#### Security

When saved to disk, the container is encrypted with the AES-256 symmetric encryption algorithm using the CBC mode of operation. The 256 bit AES key is derived from the user entered password by the PBKDF2 key derivation algorithm using the SHA-512 hash algorithm, with 100,000 iterations, and using a 256 bit random salt value generated by the Windows CAPI.

The password derived AES key is set on creation of the container and changed on the user initiated password change operation. A new AES IV is generated on each save of the container, generated by the Windows CAPI.

The password length does not have an arbitrary upper limit, and can contain any characters representable in UTF-8. The lower limit of the password length is 1 character, but a message is displayed when setting the password to a value that is under 16 characters, encouraging the user to select a stronger password – however this is only a suggestion.

#### Menu Items

##### Container -> New

Creates a new container. Prompts user to set a password. Opens the container for use.

Note: The current container must be closed before performing this operation.

Note: The container is not automatically saved – you must use Container -> Save or Container -> Save As to save the container to disk.

##### Container -> Open

Opens an existing container from disk. Prompts user to enter a password to decrypt the container.

Note: The current container must be closed before performing this operation.

##### Container -> Edit

Opens the Edit Container window to modify the container’s contents.

Note: The current container must already be open before performing this operation.

##### Container -> Change Password

Prompts user to change the container’s password. Displays the

Note: The current container must already be open before performing this operation.

##### Container -> Save

Saves the current container to disk. If the container was opened from disk, it will overwrite that container on disk. If the container was created, the user will be prompted to select a location to save the container.

Note: The current container must already be open before performing this operation.

##### Container -> Save As

Saves the current container to disk. Prompts the user to select a location to save the container.

Note: The current container must already be open before performing this operation.

##### Container -> Close

Closes the current container. If the container has been modified, prompts the user to choose whether to save the container or not.

Note: The current container must already be open before performing this operation.

#### Windows

##### Edit Container

###### Keys

Options are the same as in P25 KFD -> Keyload, with the exception of the text box Name and button Save.

###### Name

The name text box defines a name for the key.

Note: The key name is required.

Note: The key name must be unique.

###### Save

The save button saves the key parameters.

###### Groups

###### Name

The name text box defines a name for the group.

Note: The group name is required.

Note: The group name must be unique.

###### Available

The available list displays the available keys from the key container.

###### Selected

The selected list displays the available keys from the key container.

###### Add

When a key is selected in the available column, moves the key to the selected column.

###### Remove

When a key is selected in the selected column, moves the key to the available column.

###### Save

The save button saves the group parameters.

###### New

Creates a new key or group depending on the tab selected.

###### Up

Moves the selected key or group up in the list.

###### Down

Moves the selected key or group down in the list.

###### Delete

Deletes the selected key or group.

### Type

#### Overview

The type menu allows for the selection of the device type used to communicate with the target. The Type menu’s selection influences the options available in the Device menu.

#### Menu Items

##### TWI (KFDtool)

Selects the TWI protocol with a connection to the target device via the KFDtool USB adapter.

##### DLI (IP)

Selects the DLI (IP) protocol with a connection to the target device via the internal Windows IP stack. The target device can be over any interface that is reachable by a route in the Windows IP routing table – for example, RNDIS over USB or PPP over serial.

### Device

#### Overview

The device menu allows for the selection of the device used to communicate with the target. It displays different options depending on the Type menu’s selection.

#### Menu Items

##### When Type is TWI (KFDtool)

Contains a list of connected KFDtool USB adapters by COM port. When no adapters are connected, displays ‘No devices found’.

##### When Type is DLI (IP)

Contains only the option [Edit]. Opens the DLI (IP) Connection Settings window. Only one configuration is supported at this time.

#### Windows

##### DLI (IP) Connection Settings

###### Protocol

The protocol selection is used as the transport layer on the IP network layer. At this time, the only selection is UDP.

Note: This selection is set by default to UDP, the protocol used by Motorola devices.

###### Hostname

The hostname field is used to determine the IP address of the target device. It can either be set to a host name and be resolved, or set to the IP address directly. Both IPv4 and IPv6 addresses are supported.

Note: This field is required.

Note: This field is set by default to 192.168.128.1, the default IP address used by Motorola devices.

###### Port

The port field is used as the protocol’s destination port.

Note: This field is required.

Note: The valid port range is 1-65535.

Note: This field is set by default to 49644, the default port used by Motorola devices.

###### Variant

The variant selection is used to change the behavior of the DLI protocol, as some vendor’s devices do not follow the P25 standard, and require non-standard behavior to operate properly.

The selections are either Standard or Motorola. The Standard variant conforms to the P25 standard. The Motorola variant deviates from the P25 standard to operate correctly with Motorola devices.

Note: This selection is set by default to Motorola, the variant used by Motorola devices.

### P25 KFD

#### Overview

TODO

#### Menu Items

##### P25 KFD -> Multiple Keyload

###### Keys

###### Available

The available list displays the available keys from the key container.

###### Selected

The selected list displays the available keys from the key container.

###### Add

When a key is selected in the available column, moves the key to the selected column.

###### Remove

When a key is selected in the selected column, moves the key to the available column.

###### Groups

###### Available

The available list displays the available groups from the key container.

###### Selected

The selected list displays the available groups from the key container.

###### Add

When a group is selected in the available column, moves the group to the selected column.

###### Remove

When a group is selected in the selected column, moves the group to the available column.

###### Load

The load button loads the selected keys/groups into the target device.

##### P25 KFD -> Keyload

###### Keyset ID

The Keyset ID text box is used to specify the keyset to use.

Note: The Keyset ID is required if Active Keyset is not checked.

Note: When Active Keyset is checked, this field is disabled as the keyset is automatically determined during the keyload operation.

###### Active Keyset

The Active Keyset check box is used to specify whether to use the target device’s current keyset (checked), or to use the keyset specified in the Keyset ID field (unchecked).

###### SLN/CKR

The SLN/CKR text box is used to specify the SLN or CKR to use.

Note: The SLN/CKR is required.

###### Key Type

The Key Type combo box is used to specify what type of key is to be loaded. The selection Auto automatically selects the key type based on the SLN/CKR specified. The selection TEK forces the key type to a KEK, and the selection KEK forces the key type to a KEK.

Note: The Key Type is required.

Note: When the Auto option is selected, the label besides the combo box displays the key type in real time based on the current SLN/CKR value.

###### Key ID

The Key ID text box is used to specify the key ID to use.

Note: The Key ID is required.

###### Algorithm

The Algorithm text box is used to specify the algorithm to use. The combo box to the right of the text boxes contains commonly used algorithm options.

Note: The Algorithm is required.

Note: If the algorithm combo box has a selection other than Other, the algorithm text boxes are disabled, and the currently selected algorithm preset value is shown in them.

###### Key

The key text box is used to specify the encryption key to load into the target. It may only contain hex characters (0-9, A-F, a-f), with a length divisible by 2.

Note: The Key is required.

###### Hide

The hide check box is used to hide the entered key from view. When checked (default), the key is hidden. When unchecked, the key is visible.

###### Generate

The generate button is used to generate an encryption key. The parameters of the generated key is based on the Algorithm selection.

Note: The generate function only works with the algorithms AES-256, DES-OFB, DES-XL, ADP/RC4.

###### Load

The load button loads the key into the target device.

##### P25 KFD -> Key Erase

TODO

##### P25 KFD -> Erase All Keys

TODO

##### P25 KFD -> View Key Info

TODO

##### P25 KFD -> View Keyset Info

TODO

##### P25 KFD -> RSI Configuration

TODO

##### P25 KFD -> KMF Configuration

TODO

### P25 MR

#### Overview

TODO

#### Menu Items

##### P25 MR-> Emulator

TODO

### Utility

#### Overview

TODO

#### Menu Items

##### Utility -> Fix DES Key Parity

TODO

##### Utility -> Update Adapter Firmware

TODO

##### Utility -> Initialize Adapter

TODO

##### Utility -> Adapter Self Test

TODO

# Glossary

ADP – Advanced Digital Privacy

AES – Advanced Encryption Standard

CAPI – Cryptographic Application Programming Interface

CBC – Cipher block chaining

CKR – Common Key Reference

DES – Data Encryption Standard

DLI – Data Link Independent

IP – Internet Protocol

IPv4 – Internet Protocol Version 4

IPv6 – Internet Protocol Version 6

IV – Initialization Vector

KEK – Key Encryption Key

KFD – Key Fill Device

P25 – Project 25

PBKDF2 – Password-Based Key Derivation Function 2

PDF – Portable Document Format

PPP – Point-to-Point Protocol

RC4 – Rivest Cipher 4

RNDIS – Remote Network Driver Interface Specification

SLN – Storage Location Number

TEK – Traffic Encryption Key

TWI – Three-Wire Interface

UDP – User Datagram Protocol

USB – Universal Serial Bus

UTF-8 – 8-bit Unicode Transformation Format

KFDtool Software Manual Manual for Version 1.5.0 (Manual Revision 1)

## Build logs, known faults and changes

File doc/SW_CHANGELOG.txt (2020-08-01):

KFDtool SW 1.5.0 (2020-08-01)

* Fix regression affecting MR emulation with Motorola KVL4000 (issue #31)
* Add support for key container (issue #3)
* Add manual (issue #1)
* Update NLog package version

KFDtool SW 1.4.0 (2020-05-17)

* Add support for DLI over IP devices (issue #18)
* Add optional manual rekeying features (issue #9)
* Add multiple key support to lower rekeying layers (issue #2)
* Update NLog and Mono.Options package versions

KFDtool SW 1.3.2 (2020-03-15)

* Fix 3WI session not ending cleanly after error (issue #20)
* Fix KEK keyloading failure (issue #21)

KFDtool SW 1.3.1 (2020-01-01)

* Fix MR emulation compatibility with Motorola KVL4000 (issue #17)
* Fix crash when stopping MR emulator with no device (issue #15)

KFDtool SW 1.3.0 (2019-12-29)

* Add MR emulation functionality
* Use keyset 1 when no keysets exist and use active keyset is selected
* Add MR detection functionality
* Improve adapter protocol version validation

KFDtool SW 1.2.0 (2019-10-12)

* Include command line utility in binaries and installers
* Add DES key parity calculator feature

KFDtool SW 1.1.1 (2019-09-04)

* Fix Windows version check always failing on x86 installer

KFDtool SW 1.1.0 (2019-08-30)

* Add installer
* Read all keys in view key info
* Fix error on adapter first connection not finding port number
* Hide key by default in keyload
* Show both dec and hex algorithm id in keyload
* Show adapter information on status bar
* Show name of algorithm in view key info
* Add help menu manual item
* Add digital signature to driver

KFDtool SW 1.0.0 (2019-07-29)

* Initial release

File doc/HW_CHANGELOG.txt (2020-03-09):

KFDtool HW 2020-03-08

* Update BOM to add AC107A

KFDtool HW 2020-01-18

* Update BOM to add AC104B, AC105A, AC106A

KFDtool HW 2019-10-12

* Add PT100 REV D
* PT100 REV D: Fix D1, D2, Q1, Q2 pin 2/3 swap
* PT100 REV D: Add USB ESD protection
* PT100 REV D: Replace LED1 GND pin thermal relief spokes with trace
* Update BOM to add KFD100 HW REV 1.1, AC102A, AC103A, AC104A

KFDtool HW 2019-07-29

* Initial release

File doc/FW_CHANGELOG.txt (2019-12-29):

KFDtool FW 1.3.0 (2019-12-28)

* Fix data being returned before bus returns to idle
* Change GPIO pin assignments to match production PCB

KFDtool FW 1.2.0 (2019-10-12)

* Add support for hardware revision 1.1

KFDtool FW 1.0.0 (2019-07-29)

* Initial release

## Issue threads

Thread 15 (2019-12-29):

MR emulator will allow start with no device selected

duggerd, 2019-12-29:
With no device selected, the UI will permit you to press the 'Start' button with no error message. The interface will act normally, and will permit you to press 'Stop' with no error message.

Add a check to show an error when no device is selected and 'Start' is pressed.

Closed 2019-12-31.

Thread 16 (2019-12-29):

Firmware upgrade fails occasionally

duggerd, 2019-12-29:
Firmware upgrades or unit initializations will occasionally fail with an error message, or the GUI will just hang indefinitely.

CPU usage is high during the upgrade process, which might be a factor.

Add automatic recovery attempts, as well as display a message pointing to documentation on how to recover the unit manually.

Document in the manual how to recover the unit manually.

duggerd, 2019-12-29:
Manual recovery instructions:

1. Disconnect the KFDtool unit from the USB port
2. While holding the recessed button besides the USB port with a paper clip or similar, plug the USB cable in
3. Navigate to the Utility->Initialize Adapter page in the KFDtool software
4. Select the firmware upgrade file
5. Select the model and hardware revision number that is printed on the label on the top of the unit from the drop down selection
6. Click 'Initialize'
7. Click OK to the warnings that pop up
8. A message should appear after a few seconds stating the firmware has been loaded successfully

If a message appears stating there are no devices connected in BSL mode, perform steps 1 and 2 again. You should hear a USB device detected chime from Windows when the device is connected.

mattames, 2020-03-16:
@duggerd this issue popped up for one of the earlty adopters - looks like this is the only place the fix is documented too.

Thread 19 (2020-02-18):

Add support for operations encapsulated in encryption

duggerd, 2020-02-18:
To allow support for radios and keyloaders in FIPS compliance required modes.

Attempting to keyload an APX radio with FIPS mode enabled results in an invalid status message. Disabling FIPS mode is currently the recommended workaround.

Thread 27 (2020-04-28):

Key Encryption Key (KEKs)

kategray, 2020-04-28:
Hello,

I was wondering if there would be any interest in adding support for Key Encryption Keys to the MSP430 firmware.  It's something I could probably put together easy enough once the hardware goes on sale, and it would make it possible to protect the keys from the host system.

There's a couple ways it could be handled on the host side, like supporting an encrypted blob (easiest) that's decrypted on device, or even using PKCS11 to wrap and/or derive keys (which would let a smart card or HSM be used).

It's not going to be perfect security - the MSP430 isn't really hardened against differential power analysis, for example, but it would be a step towards not needing to trust the host.

duggerd, 2020-05-02:
Hi Kate,

Support for keyloading with the P25 definition of KEKs over the keyloading interface is tracked under issue #19 - I'm assuming that's what you mean.

The KFDtool hardware isn't anything more than a USB to serial converter that works with the special bidirectional keyloading interface - all the key management messages are generated on the computer in software. Only single bytes are passed over the USB interface. For ease of development and debugging, I've tried to keep as much functionality in the software as possible, and only the bare minimum in the firmware.

You would first need to port a lot of the 3WI/KMM framing code from the software (C#) side to the firmware (C) side before being able to add the 3WI KEK encapsulation to the firmware.

The security model of the KFDtool expects the host computer, adapter, and radio to be trustworthy - there really isn't a way to secure the keys through all the layers of the (KFDtool software, .NET runtime, Windows USB stack, USB host controller driver, etc) with the model of the computer generating the KMMs.

At the end of the day something has to have access to the plaintext keys, as the IVs are random per session - so without a hardened adapter (potted, tamper flex, keys in RAM and micro powered by a supercap, micro designed for crypto use, hardware rng, signed firmware updates, disabled in circuit programming interfaces, etc) it would be trivial to extract the keys by modifying the firmware. Though even then the adapter could be replaced with another with different firmware from the start that could covertly retain the keys.

I do plan on adding KEKs on the software side, as it's required for interoperability with FIPS mode enforced which requires all operations to be encapsulated with encryption. I'd honestly prefer effort be put into adding it to the software first before the firmware, as the added security isn't really much by putting it in the firmware.

Regards,

Daniel

kategray, 2020-05-21:
Hello,

That wasn’t quite what I was talking about.  I do a fair amount of work with very constrained HSMs, which have just enough memory to store a master key.  They offload most of the work to the host (including storage), and decrypt the blobs provided by the host PC when needed to work with them.  Generally, firmware updates require clearing all the data, which helps avoid the problem of malicious firmware.

It would absolutely require rewriting the key generation portion of the system.

The main goal would be to protect against the host computer getting infected by keeping all the plaintext keys out of it.  If the computer had only encrypted key blobs, and the key was retained in the MSP430 which uses TI’s CryptoBSL, it would be very difficult for a digital-only attacker to accomplish much.

Such a s system is also useful from a department standpoint, as it makes it very easy for a tech to import or program keys, but requires relatively specialized knowledge and/or equipment to obtain the keys and disclose them to others.

duggerd, 2020-05-21:
Ah, I see what you mean - sorry for the misunderstanding.

It looks like the CryptoBSL is only available for MSP430FR59xx and MSP430FR69xx FRAM microcontrollers, where the current KFDtool hardware uses a MSP430F5529 flash microcontroller. The FRAM devices aren't a good choice in the overall security objective as the RAM isn't cleared on powerdown automatically like the MSP430F5529 device does with traditional RAM.

The MSP430 bootloader is stored in flash memory with user code, as well as some persistent info like the KFDtool model number, hardware revision number, and serial number. However, some customization of the TI provided BSL could capture the persistent IDs, erase the entire flash, write the BSL/firmware, and then write the persistent IDs once completed. The user would have to inspect the hash of the firmware file to determine if it is trustworthy.

However, with the current hardware, either entering BSL mode through software, or through hardware still puts the device into user code from the last firmware update, which could just report it erased the old firmware where it really did not. I'm thinking a new hardware design with security in mind from the start would be needed. With this being an open source project, I'm reluctant in having a firmware signing key that's kept secret and doesn't allow anyone except from me to sign releases, so that would have to be worked around.

So you would be adding a function in the firmware to import and store a key encryption key internally. Then another function would take the plaintext key from the software, encrypt it with that key encryption key, and return the encrypted key to the software. And then on subsequent keyload operations, the software would transmit the encrypted key to the firmware, which would then decrypt it with the key encryption key, and send it out the keyload interface.

Something that would help with the amount of code needing to be rewritten is the KFDtool software could handle all the keyloading protocol, except when it would normally send the key data, it would send a command to the firmware to send the key bytes, then the software would then go back to handling the rest of the transaction.

Therefore the only new opcodes needed on the firmware side are:

1. Import key encryption key, input plaintext key, output none
2. Encrypt key, input plaintext key, output encrypted key
3. Send key, input encrypted key, output plaintext key over keyload interface

The key encryption key would still pass through the PC, so initially you would still need to trust the PC, as well as when new keys are added. Though the KEK could be generated in the firmware, as well as any new TEKs and not exported for extra security.

This would require some more work for encapsulated operations with P25 KEKs, though it could be similar but the firmware could handle the outer layer encryption in the same way.

I can see how this can help with data at rest, but once the device is activated for keyload, it has to transfer the symmetric TEK to the target device for keyload. Another KFDtool unit in MR emulation mode, or in listen only mode could capture the key. Keyload operations encapsulated in KEKs would only be safe if the monitoring unit didn't know the KEK used. However, the KEKs have to be loaded in plaintext when the radio is first put into service, so there is an opportunity to obtain them there. I suppose the person loading the KEKs would have to be completely trusted, but further loading of TEKs could be done with a unit that is technically contained to only allow TEK keyloading with a KEK. That would allow units to be issued to techs without them being able to to recover the raw TEKs, only load them into targets with KEKs already provisioned.

kategray, 2020-08-11:
> With this being an open source project, I'm reluctant in having a firmware signing key that's kept secret and doesn't allow anyone except from me to sign releases, so that would have to be worked around.

The HSMs I work with are based on the old Android unlocking security model.  The device ships secure (and signed), and you are free to unlock it if you want.  Doing so just wipes any stored keys.  I rather like this model, as it preserves complete openness, while allowing those who want increased security to have it.

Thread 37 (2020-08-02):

Exit menu item does not match window close button behavior

duggerd, 2020-08-02:
When user requests program exit through the window close button, it will ask to save the container if it is unsaved/prevent exit if the MR emulator is running. The exit menu item will display the dialogs, but will not prevent exit. This is due to the Application.Current.Shutdown() function used in the Exit_MenuItem_Click() function, rather than the Close() function.

Also return after preventing exit due to the MR emulator.

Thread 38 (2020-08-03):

Migrate from .NET Framework to .NET Core

duggerd, 2020-08-03:
Move to .NET Core and drop .NET Framework dependency.

Blocked by rewrite of firmware update module in issue #16.

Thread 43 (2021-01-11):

Clarify Self Test Warning Dialog

duggerd, 2021-01-11:
Currently when running the self test, the dialog says to disconnect the radio, however the cable and radio adapter should also be disconnected. The self test feature is only designed to test the unit, not the cable or any radio adapters. When running the self test with some radio adapters, the self test will report a failure when the unit is actually functioning properly.

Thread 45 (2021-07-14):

KFDtool

hysamrashed, 2021-07-14:
Now it's not available on it's site and now can i encrypt icom with the program directly with out device

duggerd, 2021-07-14:
The KFDtool KFD100 is currently out of stock at this time due to parts that are required to manufacture the unit not being available at this time due to the global component shortage. Once those components are available again, another batch will be manufactured and available in the KFDtool store.

If you would like to be notified of when they are back in stock, please email contact@store.kfdtool.com

As the KFDtool KFD100 adapter acts as an interface between the KFDtool software and the radio's hardware, it isn't possible to keyload a radio without the adapter.

RivasMario, 2022-12-12:
is there a SOP on keyloading with out the hardware?

Caper123, 2022-12-15:
Kenwood KPG-93 cable. To make your own KPG-93 cable AC106A. It mentions Accessory Pin 13, (Cathode) Schottky Diode (Anode)  could you please provide  the values for the  needed components. Or is there a schematic available?

Thank you

bigfella237, 2023-03-13:
Almost two years sent I sent an email requesting to be notified when available... and THEY'RE STILL NOT AVAILABLE!

Is there any ETA on the KFDtool being back in stock? Surely the world has sufficiently recovered from COVID that components are being manufactured again?

This is very frustrating. I don't want a Chinese knock-off, I don't really want to build one using an Arduino, I just want to buy something that works!

blackhelicoptersdotnet, 2023-03-13:
> Surely the world has sufficiently recovered from COVID that components are being manufactured again?

oh boy do I have a surprise for you

Chewy-13, 2023-03-13:
>I don't really want to build one using an Arduino, I just want to buy something that works!

I wouldn't really call it building. It was a piece of cake, especially if you're able to follow instructions.

bigfella237, 2023-03-14:
> oh boy do I have a surprise for you

If a manufacturer closed down because of COVID and hasn't re-opened by now, I'd suggest that they aren't going to re-open.

Time to seek alternate suppliers.

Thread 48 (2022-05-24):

Error Message on Portable Radio read/write

ncso935, 2022-05-24:
KFD- Shield
FW 1.4.0
SW 1.5.4

When connected to a mobile (APX 6500) reads keys and writes keys with no issue.

Same cable connected an APX portable (APX 6000 x3 radios and APX 8000 x2 radios) gives error message and does not perform the job.

Error message:    Error-- timeout waiting for data

Same hirose radio adapter used with KVL5000 has no issues. Same cable for both mobile and portable, just swapping the end adapter.

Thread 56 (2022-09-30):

DLI Not working?

DevRanger, 2022-09-30:
I've tried 3 installs on 3 different devices, none of them are working. DLI was working on an older build (for me at least) and after updating to latest, it stopped working.

Device: APX 900 (SW AES Enabled on flash)
KFDTool Ver: Latest (as of submission of this issue)
Issue: See image
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

Windows detects the radio, pops up the network thing that it does when you connect an APX and CPS works fine so I know its not my cable or my system?

duggerd, 2022-09-30:
What is the APX 900 FW version?

Also confirm these settings in CPS:

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

duggerd, 2022-09-30:
As well as:

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

duggerd, 2022-09-30:
I tested a radio running R27.00.01 and it worked using the current KFDtool release 1.5.0 on Windows 10 x64.

Can you ping the radio at 192.168.128.1? That error message you are getting appears when the radio is not responding at all.

Also one more setting to check:

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

DevRanger, 2022-09-30:
When I attempt to ping 192.168.128.1 (the radio's IP) it times out. Tested across my 3 devices and 2 separate prog cables.

Systems are on win 10 x64 build 21H2

The systems see the APX connected, popup the normal network thing that windows does (then I click "allow") and I see the radio network in task manager. CPS & tuner work fine, KFDTool just isint seeing it.

I've been trying to figure out why its not working for the past few weeks but at this point I feel like I've eliminated the computers and my prog cables being the issue...

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

duggerd, 2022-09-30:
If you can't ping the radio, that would be the larger problem. For some reason your machines are acting differently than a typical install.

Is there any firewall or antivirus software installed on these machines?

Does ipconfig /all show this for the radio?

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

duggerd, 2022-09-30:
Yikes...something is up with that radio.

It explains the CPS/Tuner working but not KFDtool. CPS/Tuner dynamically queries Windows to discover the IP address of the radio. KFDtool uses a default of 192.168.128.1. I bet if you go in KFDtool, Device -> Edit, and change 192.168.128.1 to 208.27.88.51, it will work.

DevRanger, 2022-09-30:
right as you were responding, i tried that and it worked lol. thank you for the help!!!

Closed 2022-09-30.

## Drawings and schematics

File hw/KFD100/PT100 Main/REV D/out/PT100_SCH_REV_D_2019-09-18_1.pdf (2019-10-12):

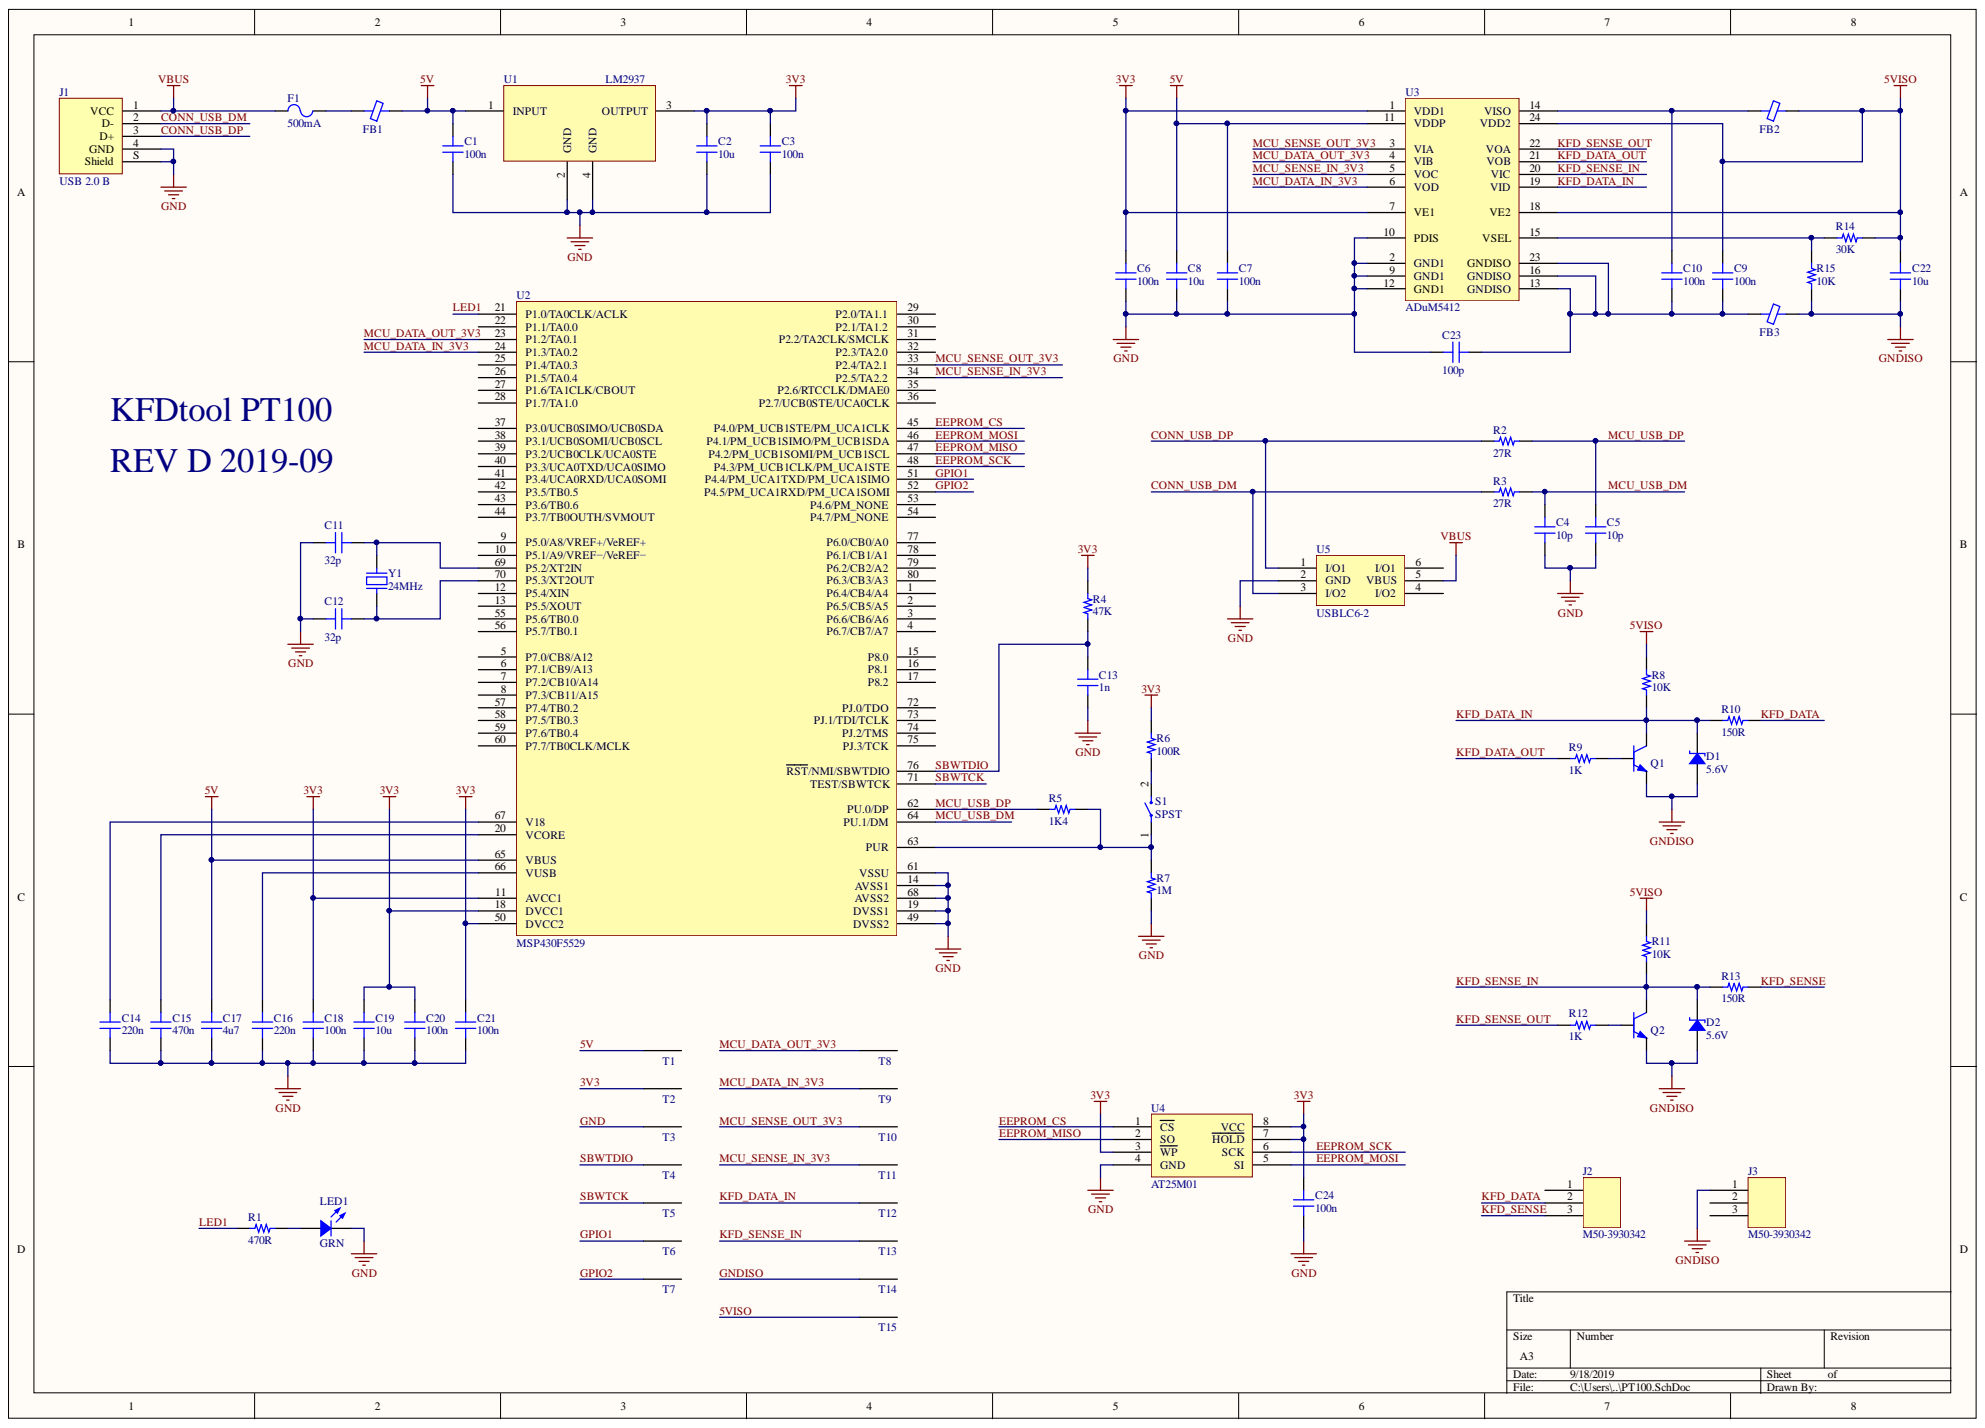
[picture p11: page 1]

GND1 2

GND1 12

VCORE 20

VBUS 65
VUSB 66

AVCC1 11

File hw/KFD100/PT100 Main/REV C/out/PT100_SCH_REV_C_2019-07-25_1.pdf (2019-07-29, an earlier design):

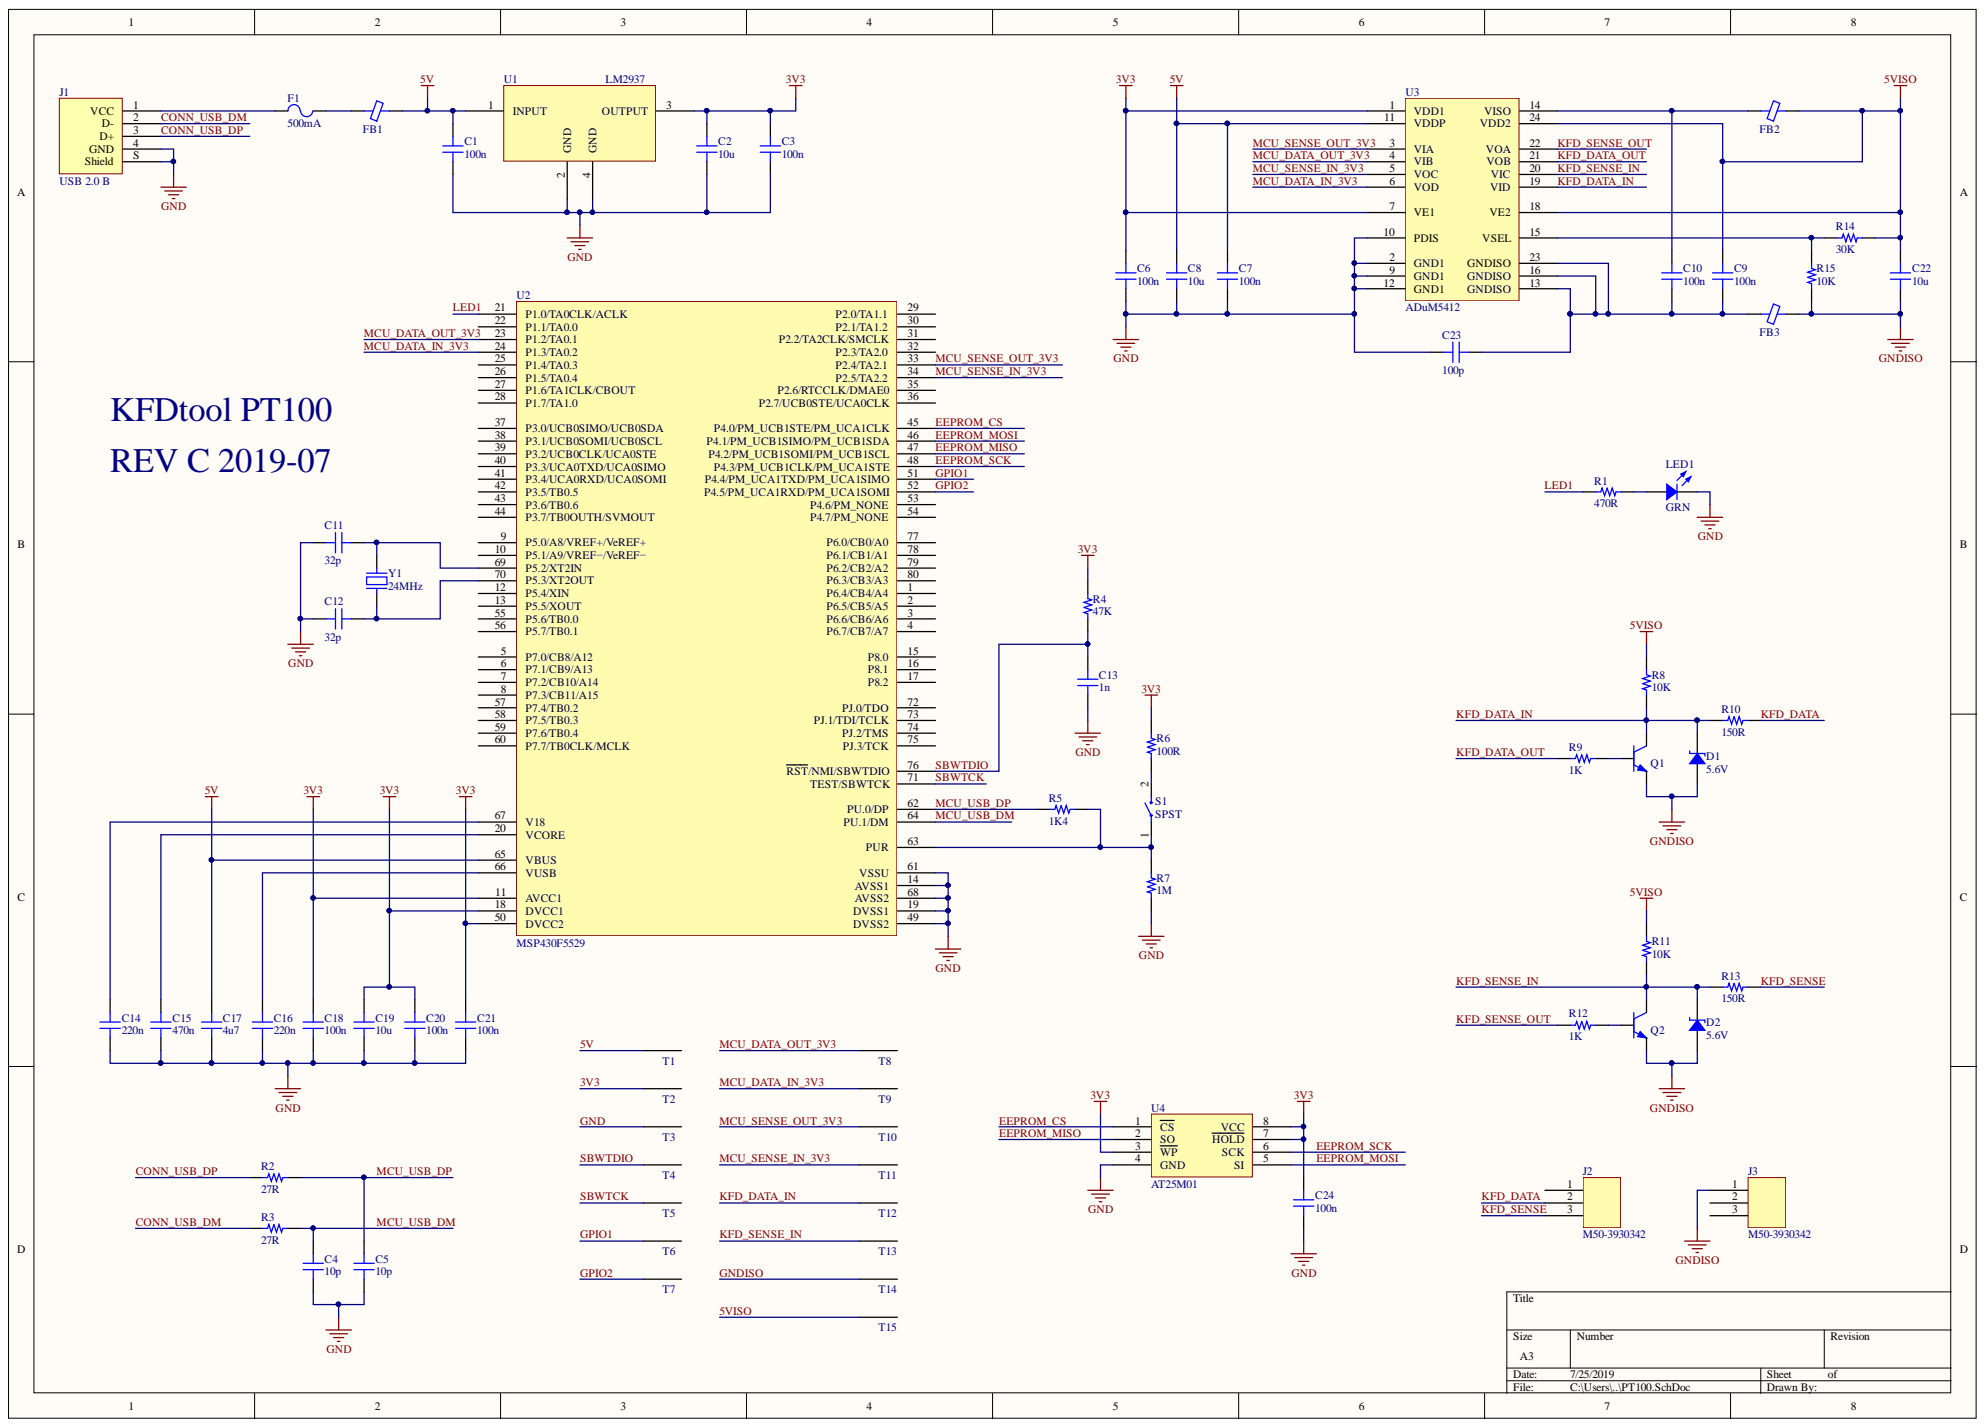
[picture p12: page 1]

GND1 2

GND1 12

VCORE 20

VBUS 65
VUSB 66

AVCC1 11

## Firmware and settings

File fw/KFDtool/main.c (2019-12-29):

// KFDtool
// Copyright 2019 Daniel Dugger

// MSP430 Driver Library Version 2.91.11.01 2019-02-20
// MSP430 USB Stack Version ???

#include "driverlib.h"

#include "hal.h"
#include "TwiProtocol.h"
#include "SerialProtocol.h"
#include "InfoData.h"

/* FIRMWARE VERSION */
#define VER_FW_MAJOR 0x01
#define VER_FW_MINOR 0x03
#define VER_FW_PATCH 0x00

/* ADAPTER PROTOCOL VERSION */
#define VER_AP_MAJOR 0x01
#define VER_AP_MINOR 0x00
#define VER_AP_PATCH 0x00

/* COMMAND OPCODES */
#define CMD_READ 0x11
#define CMD_WRITE_INFO 0x12
#define CMD_ENTER_BSL_MODE 0x13
#define CMD_RESET 0x14
#define CMD_SELF_TEST 0x15
#define CMD_SEND_KEY_SIG 0x16
#define CMD_SEND_BYTE 0x17

/* RESPONSE OPCODES */
#define RSP_ERROR 0x20
#define RSP_READ 0x21
#define RSP_WRITE_INFO 0x22
#define RSP_ENTER_BSL_MODE 0x23
#define RSP_RESET 0x24
#define RSP_SELF_TEST 0x25
#define RSP_SEND_KEY_SIG 0x26
#define RSP_SEND_BYTE 0x27

/* BROADCAST OPCODES */
#define BCST_RECEIVE_BYTE 0x31

/* READ OPCODES */
#define READ_AP_VER 0x01
#define READ_FW_VER 0x02
#define READ_UNIQUE_ID 0x03
#define READ_MODEL_ID 0x04
#define READ_HW_REV 0x05
#define READ_SER_NUM 0x06

/* WRITE OPCODES */
#define WRITE_MDL_REV 0x01
#define WRITE_SER 0x02

/* ERROR OPCODES */
#define ERR_OTHER 0x00
#define ERR_INVALID_CMD_LENGTH 0x01
#define ERR_INVALID_CMD_OPCODE 0x02
#define ERR_INVALID_READ_OPCODE 0x03
#define ERR_READ_FAILED 0x04
#define ERR_INVALID_WRITE_OPCODE 0x05
#define ERR_WRITE_FAILED 0x06

uint16_t cmdCount;
uint8_t cmdData[128];
uint16_t rxReady;
uint8_t rxTemp;

void main(void)
{
    WDT_A_hold(WDT_A_BASE);

    halInit();
    spConnect();

    __enable_interrupt();

    twiInit();

    halLed1On();

    while (1)
    {
        cmdCount = spRxData(cmdData);

        if (cmdCount > 0)
        {
            if (cmdData[0] == CMD_READ) // read
            {
                if (cmdCount == 2)
                {
                    if (cmdData[1] == READ_AP_VER) // read adapter protocol version
                    {
                        uint8_t rspData[5];

                        rspData[0] = RSP_READ;
                        rspData[1] = READ_AP_VER;
                        rspData[2] = VER_AP_MAJOR;
                        rspData[3] = VER_AP_MINOR;
                        rspData[4] = VER_AP_PATCH;

                        spTxDataWait(rspData, sizeof(rspData));
                    }
                    else if (cmdData[1] == READ_FW_VER) // read firmware version
                    {
                        uint8_t rspData[5];

                        rspData[0] = RSP_READ;
                        rspData[1] = READ_FW_VER;
                        rspData[2] = VER_FW_MAJOR;
                        rspData[3] = VER_FW_MINOR;
                        rspData[4] = VER_FW_PATCH;

                        spTxDataWait(rspData, sizeof(rspData));
                    }
                    else if (cmdData[1] == READ_UNIQUE_ID) // read unique id
                    {
                        uint8_t* serNum;
                        uint8_t serLen;

                        serNum = 0;

                        TLV_getInfo(TLV_TAG_DIERECORD, 0, (uint8_t *)&serLen, (uint16_t **)&serNum);

                        if (serLen == 10)
                        {
                            uint8_t rspData[12];

                            rspData[0] = RSP_READ;
                            rspData[1] = READ_UNIQUE_ID;
                            rspData[2] = 0x09; // id length
                            rspData[3] = 0x10; // id source (msp430 die record)
                            rspData[4] = *serNum; // id[0]
                            serNum++;
                            rspData[5] = *serNum; // id[1]
                            serNum++;
                            rspData[6] = *serNum; // id[2]
                            serNum++;
                            rspData[7] = *serNum; // id[3]
                            serNum++;
                            rspData[8] = *serNum; // id[4]
                            serNum++;
                            rspData[9] = *serNum; // id[5]
                            serNum++;
                            rspData[10] = *serNum; // id[6]
                            serNum++;
                            rspData[11] = *serNum; // id[7]

                            spTxDataWait(rspData, sizeof(rspData));
                        }
                        else // no unique id available
                        {
                            uint8_t rspData[3];

                            rspData[0] = RSP_READ;
                            rspData[1] = READ_UNIQUE_ID;
                            rspData[2] = 0x00; // id length

                            spTxDataWait(rspData, sizeof(rspData));
                        }
                    }
                    else if (cmdData[1] == READ_MODEL_ID) // read model id
                    {
                        uint16_t status;
                        uint8_t hwId;

                        status = idReadModelId(&hwId);

                        if (status) // check if available
                        {
                            uint8_t rspData[3];

                            rspData[0] = RSP_READ;
                            rspData[1] = READ_MODEL_ID;
                            rspData[2] = hwId;

                            spTxDataWait(rspData, sizeof(rspData));
                        }
                        else // no model id available
                        {
                            uint8_t rspData[3];

                            rspData[0] = RSP_READ;
                            rspData[1] = READ_MODEL_ID;
                            rspData[2] = 0x00;

                            spTxDataWait(rspData, sizeof(rspData));
                        }
                    }
                    else if (cmdData[1] == READ_HW_REV) // read hardware revision
                    {
                        uint16_t status;
                        uint8_t hwRevMaj;
                        uint8_t hwRevMin;

                        status = idReadHwRev(&hwRevMaj, &hwRevMin);

                        if (status == 1) // check if available
                        {
                            uint8_t rspData[4];

                            rspData[0] = RSP_READ;
                            rspData[1] = READ_HW_REV;
                            rspData[2] = hwRevMaj;
                            rspData[3] = hwRevMin;

                            spTxDataWait(rspData, sizeof(rspData));
                        }
                        else // no hardware revision available
                        {
                            uint8_t rspData[4];

                            rspData[0] = RSP_READ;
                            rspData[1] = READ_HW_REV;
                            rspData[2] = 0x00;
                            rspData[3] = 0x00;

                            spTxDataWait(rspData, sizeof(rspData));
                        }
                    }
                    else if (cmdData[1] == READ_SER_NUM) // read serial number
                    {
                        uint16_t status;
                        uint8_t ser0;
                        uint8_t ser1;
                        uint8_t ser2;
                        uint8_t ser3;
                        uint8_t ser4;
                        uint8_t ser5;

                        status = idReadSerNum(&ser0, &ser1, &ser2, &ser3, &ser4, &ser5);

                        if (status == 1) // check if available
                        {
                            uint8_t rspData[9];

                            rspData[0] = RSP_READ;
                            rspData[1] = READ_SER_NUM;
                            rspData[2] = 0x06; // serial length
                            rspData[3] = ser0;
                            rspData[4] = ser1;
                            rspData[5] = ser2;
                            rspData[6] = ser3;
                            rspData[7] = ser4;
                            rspData[8] = ser5;

                            spTxDataWait(rspData, sizeof(rspData));
                        }
                        else // no serial number available
                        {
                            uint8_t rspData[3];

                            rspData[0] = RSP_READ;
                            rspData[1] = READ_SER_NUM;
                            rspData[2] = 0x00; // serial length

                            spTxDataWait(rspData, sizeof(rspData));
                        }

                    }
                    else // invalid read opcode
                    {
                        uint8_t rspData[2];

                        rspData[0] = RSP_ERROR;
                        rspData[1] = ERR_INVALID_READ_OPCODE;

                        spTxDataWait(rspData, sizeof(rspData));
                    }
                }
                else // invalid command length
                {
                    uint8_t rspData[2];

                    rspData[0] = RSP_ERROR;
                    rspData[1] = ERR_INVALID_CMD_LENGTH;

                    spTxDataWait(rspData, sizeof(rspData));
                }
            }
            else if (cmdData[0] == CMD_WRITE_INFO) // write info
            {
                if (cmdCount > 1)
                {
                    if (cmdData[1] == WRITE_MDL_REV) // write model id and hardware revision
                    {
                        if (cmdCount == 5)
                        {
                            uint16_t result;

                            result = idWriteModelIdHwRev(cmdData[2], cmdData[3], cmdData[4]);

                            if (result == 1)
                            {
                                uint8_t rspData[1];

                                rspData[0] = RSP_WRITE_INFO;

                                spTxDataWait(rspData, sizeof(rspData));
                            }
                            else // write failed
                            {
                                uint8_t rspData[2];

                                rspData[0] = RSP_ERROR;
                                rspData[1] = ERR_WRITE_FAILED;

                                spTxDataWait(rspData, sizeof(rspData));
                            }
                        }
                        else // invalid command length
                        {
                            uint8_t rspData[2];

                            rspData[0] = RSP_ERROR;
                            rspData[1] = ERR_INVALID_CMD_LENGTH;

                            spTxDataWait(rspData, sizeof(rspData));
                        }
                    }
                    else if (cmdData[1] == WRITE_SER) // write serial number
                    {
                        if (cmdCount == 8)
                        {
                            uint16_t result;

                            result = idWriteSerNum(cmdData[2], cmdData[3], cmdData[4], cmdData[5], cmdData[6], cmdData[7]);

                            if (result == 1)
                            {
                                uint8_t rspData[1];

                                rspData[0] = RSP_WRITE_INFO;

                                spTxDataWait(rspData, sizeof(rspData));
                            }
                            else // write failed
                            {
                                uint8_t rspData[2];

                                rspData[0] = RSP_ERROR;
                                rspData[1] = ERR_WRITE_FAILED;

                                spTxDataWait(rspData, sizeof(rspData));
                            }
                        }
                        else // invalid command length
                        {
                            uint8_t rspData[2];

                            rspData[0] = RSP_ERROR;
                            rspData[1] = ERR_INVALID_CMD_LENGTH;

                            spTxDataWait(rspData, sizeof(rspData));
                        }
                    }
                    else // invalid write opcode
                    {
                        uint8_t rspData[2];

                        rspData[0] = RSP_ERROR;
                        rspData[1] = ERR_INVALID_WRITE_OPCODE;

                        spTxDataWait(rspData, sizeof(rspData));
                    }
                }
                else // invalid command length
                {
                    uint8_t rspData[2];

                    rspData[0] = RSP_ERROR;
                    rspData[1] = ERR_INVALID_CMD_LENGTH;

                    spTxDataWait(rspData, sizeof(rspData));
                }
            }
            else if (cmdData[0] == CMD_ENTER_BSL_MODE) // enter bsl mode
            {
                if (cmdCount == 1)
                {
                    uint8_t rspData[1];

                    rspData[0] = RSP_ENTER_BSL_MODE;

                    spTxDataWait(rspData, sizeof(rspData));

                    halDelayMs(1000); // wait 1 second

                    spDisconnect(); // disconnect usb

                    halDelayMs(3000); // wait 3 seconds

                    halLed1Off();

                    halEnterBsl();
                }
                else // invalid command length
                {
                    uint8_t rspData[2];

                    rspData[0] = RSP_ERROR;
                    rspData[1] = ERR_INVALID_CMD_LENGTH;

                    spTxDataWait(rspData, sizeof(rspData));
                }
            }
            else if (cmdData[0] == CMD_RESET) // reset
            {
                if (cmdCount == 1)
                {
                    uint8_t rspData[1];

                    rspData[0] = RSP_RESET;

                    spTxDataWait(rspData, sizeof(rspData));

                    halDelayMs(1000); // wait 1 second

                    spDisconnect(); // disconnect usb

                    halDelayMs(3000); // wait 3 seconds

                    halLed1Off();

                    halReset();
                }
                else // invalid command length
                {
                    uint8_t rspData[2];

                    rspData[0] = RSP_ERROR;
                    rspData[1] = ERR_INVALID_CMD_LENGTH;

                    spTxDataWait(rspData, sizeof(rspData));
                }
            }
            else if (cmdData[0] == CMD_SELF_TEST) // self test
            {
                if (cmdCount == 1)
                {
                    uint8_t rspData[2];

                    uint8_t result;
                    result = twiSelfTest();

                    rspData[0] = RSP_SELF_TEST;
                    rspData[1] = result;

                    spTxDataWait(rspData, sizeof(rspData));
                }
                else // invalid command length
                {
                    uint8_t rspData[2];

                    rspData[0] = RSP_ERROR;
                    rspData[1] = ERR_INVALID_CMD_LENGTH;

                    spTxDataWait(rspData, sizeof(rspData));
                }
            }
            else if (cmdData[0] == CMD_SEND_KEY_SIG) // send key signature
            {
                if (cmdCount == 2)
                {
                    twiSendKeySig();

                    uint8_t rspData[1];

                    rspData[0] = RSP_SEND_KEY_SIG;

                    spTxDataWait(rspData, sizeof(rspData));
                }
                else // invalid command length
                {
                    uint8_t rspData[2];

                    rspData[0] = RSP_ERROR;
                    rspData[1] = ERR_INVALID_CMD_LENGTH;

                    spTxDataWait(rspData, sizeof(rspData));
                }
            }
            else if (cmdData[0] == CMD_SEND_BYTE) // send byte
            {
                if (cmdCount == 3)
                {
                    twiSendPhyByte(cmdData[2]);

                    uint8_t rspData[1];

                    rspData[0] = RSP_SEND_BYTE;

                    spTxDataWait(rspData, sizeof(rspData));
                }
                else // invalid command length
                {
                    uint8_t rspData[2];

                    rspData[0] = RSP_ERROR;
                    rspData[1] = ERR_INVALID_CMD_LENGTH;

                    spTxDataWait(rspData, sizeof(rspData));
                }
            }
            else // invalid command opcode
            {
                uint8_t rspData[2];

                rspData[0] = RSP_ERROR;
                rspData[1] = ERR_INVALID_CMD_OPCODE;

                spTxDataWait(rspData, sizeof(rspData));
            }
        }

        rxReady = twiReceiveByte(&rxTemp);

        if (rxReady == 1)
        {
            uint8_t bcstData[3];

            bcstData[0] = BCST_RECEIVE_BYTE;
            bcstData[1] = 0x00; // reserved (set to 0x00)
            bcstData[2] = rxTemp;

            spTxDataBack(bcstData, sizeof(bcstData));
        }
    }
}

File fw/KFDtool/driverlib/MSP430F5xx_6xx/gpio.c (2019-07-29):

/* --COPYRIGHT--,BSD
 * Copyright (c) 2017, Texas Instruments Incorporated
 * All rights reserved.
 *
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
 * *  Redistributions of source code must retain the above copyright
 *    notice, this list of conditions and the following disclaimer.
 *
 * *  Redistributions in binary form must reproduce the above copyright
 *    notice, this list of conditions and the following disclaimer in the
 *    documentation and/or other materials provided with the distribution.
 *
 * *  Neither the name of Texas Instruments Incorporated nor the names of
 *    its contributors may be used to endorse or promote products derived
 *    from this software without specific prior written permission.
 *
 * THIS SOFTWARE IS PROVIDED BY THE COPYRIGHT HOLDERS AND CONTRIBUTORS "AS IS"
 * AND ANY EXPRESS OR IMPLIED WARRANTIES, INCLUDING, BUT NOT LIMITED TO,
 * THE IMPLIED WARRANTIES OF MERCHANTABILITY AND FITNESS FOR A PARTICULAR
 * PURPOSE ARE DISCLAIMED. IN NO EVENT SHALL THE COPYRIGHT OWNER OR
 * CONTRIBUTORS BE LIABLE FOR ANY DIRECT, INDIRECT, INCIDENTAL, SPECIAL,
 * EXEMPLARY, OR CONSEQUENTIAL DAMAGES (INCLUDING, BUT NOT LIMITED TO,
 * PROCUREMENT OF SUBSTITUTE GOODS OR SERVICES; LOSS OF USE, DATA, OR PROFITS;
 * OR BUSINESS INTERRUPTION) HOWEVER CAUSED AND ON ANY THEORY OF LIABILITY,
 * WHETHER IN CONTRACT, STRICT LIABILITY, OR TORT (INCLUDING NEGLIGENCE OR
 * OTHERWISE) ARISING IN ANY WAY OUT OF THE USE OF THIS SOFTWARE,
 * EVEN IF ADVISED OF THE POSSIBILITY OF SUCH DAMAGE.
 * --/COPYRIGHT--*/
//*****************************************************************************
//
// gpio.c - Driver for the gpio Module.
//
//*****************************************************************************

//*****************************************************************************
//
//! \addtogroup gpio_api gpio
//! @{
//
//*****************************************************************************

#include "inc/hw_memmap.h"

#ifdef __MSP430_HAS_PORT1_R__
#include "gpio.h"

#include <assert.h>

static const uint16_t GPIO_PORT_TO_BASE[] = {
    0x00,
#if defined(__MSP430_HAS_PORT1_R__)
    __MSP430_BASEADDRESS_PORT1_R__,
#elif defined(__MSP430_HAS_PORT1__)
    __MSP430_BASEADDRESS_PORT1__,
#else
    0xFFFF,
#endif
#if defined(__MSP430_HAS_PORT2_R__)
    __MSP430_BASEADDRESS_PORT2_R__,
#elif defined(__MSP430_HAS_PORT2__)
    __MSP430_BASEADDRESS_PORT2__,
#else
    0xFFFF,
#endif
#if defined(__MSP430_HAS_PORT3_R__)
    __MSP430_BASEADDRESS_PORT3_R__,
#elif defined(__MSP430_HAS_PORT3__)
    __MSP430_BASEADDRESS_PORT3__,
#else
    0xFFFF,
#endif
#if defined(__MSP430_HAS_PORT4_R__)
    __MSP430_BASEADDRESS_PORT4_R__,
#elif defined(__MSP430_HAS_PORT4__)
    __MSP430_BASEADDRESS_PORT4__,
#else
    0xFFFF,
#endif
#if defined(__MSP430_HAS_PORT5_R__)
    __MSP430_BASEADDRESS_PORT5_R__,
#elif defined(__MSP430_HAS_PORT5__)
    __MSP430_BASEADDRESS_PORT5__,
#else
    0xFFFF,
#endif
#if defined(__MSP430_HAS_PORT6_R__)
    __MSP430_BASEADDRESS_PORT6_R__,
#elif defined(__MSP430_HAS_PORT6__)
    __MSP430_BASEADDRESS_PORT6__,
#else
    0xFFFF,
#endif
#if defined(__MSP430_HAS_PORT7_R__)
    __MSP430_BASEADDRESS_PORT7_R__,
#elif defined(__MSP430_HAS_PORT7__)
    __MSP430_BASEADDRESS_PORT7__,
#else
    0xFFFF,
#endif
#if defined(__MSP430_HAS_PORT8_R__)
    __MSP430_BASEADDRESS_PORT8_R__,
#elif defined(__MSP430_HAS_PORT8__)
    __MSP430_BASEADDRESS_PORT8__,
#else
    0xFFFF,
#endif
#if defined(__MSP430_HAS_PORT9_R__)
    __MSP430_BASEADDRESS_PORT9_R__,
#elif defined(__MSP430_HAS_PORT9__)
    __MSP430_BASEADDRESS_PORT9__,
#else
    0xFFFF,
#endif
#if defined(__MSP430_HAS_PORT10_R__)
    __MSP430_BASEADDRESS_PORT10_R__,
#elif defined(__MSP430_HAS_PORT10__)
    __MSP430_BASEADDRESS_PORT10__,
#else
    0xFFFF,
#endif
#if defined(__MSP430_HAS_PORT11_R__)
    __MSP430_BASEADDRESS_PORT11_R__,
#elif defined(__MSP430_HAS_PORT11__)
    __MSP430_BASEADDRESS_PORT11__,
#else
    0xFFFF,
#endif
    0xFFFF,
#if defined(__MSP430_HAS_PORTJ_R__)
    __MSP430_BASEADDRESS_PORTJ_R__
#elif defined(__MSP430_HAS_PORTJ__)
    __MSP430_BASEADDRESS_PORTJ__
#else
    0xFFFF
#endif
};

void GPIO_setAsOutputPin(uint8_t selectedPort, uint16_t selectedPins) {

    uint16_t baseAddress = GPIO_PORT_TO_BASE[selectedPort];

    #ifndef NDEBUG
    if(baseAddress == 0xFFFF) {
        return;
    }
    #endif

    // Shift by 8 if port is even (upper 8-bits)
    if((selectedPort & 1) ^ 1) {
        selectedPins <<= 8;
    }

    HWREG16(baseAddress + OFS_PASEL) &= ~selectedPins;
    HWREG16(baseAddress + OFS_PADIR) |= selectedPins;

    return;
}
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

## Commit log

2019-08-01 Added TWI cable assembly documentation
2019-08-01 Moved driver from FW to SW directory
2019-08-01 Add TI license to SW license file for driver
2019-08-03 Add MX connector modification documentation
2019-08-27 Add digital signature to driver
2019-09-30 Crop 5 pin Amp pinout diagram
2019-10-12 Add PT100 REV D
    [KFDtool PCB Library.PcbLib, KFDtool Schematic Library.SchLib, Master BOM.xlsx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]
2019-12-28 FW: Change GPIO pin assignments to match production PCB
2019-12-31 SW: Add device presence detect to MR emulator; fixes #15
2020-01-19 HW: Add AC104B, AC105A, AC106A to BOM
    [Master BOM.xlsx]
2020-01-19 DOC: Update assembly notes for AC104B, AC105A, AC106A
2020-01-19 DOC: Update HW changelog for BOM additions
2020-03-09 DOC: Add AC107A
    [Master BOM.xlsx]
2020-03-09 DOC: Correct AC107A assembly formatting
2020-05-18 SW: Add DLI (IP) device type; fixes #18
2020-07-24 DOC: Add AC108A
    [Master BOM.xlsx]
2020-08-01 SW: Add container assembly to installer
